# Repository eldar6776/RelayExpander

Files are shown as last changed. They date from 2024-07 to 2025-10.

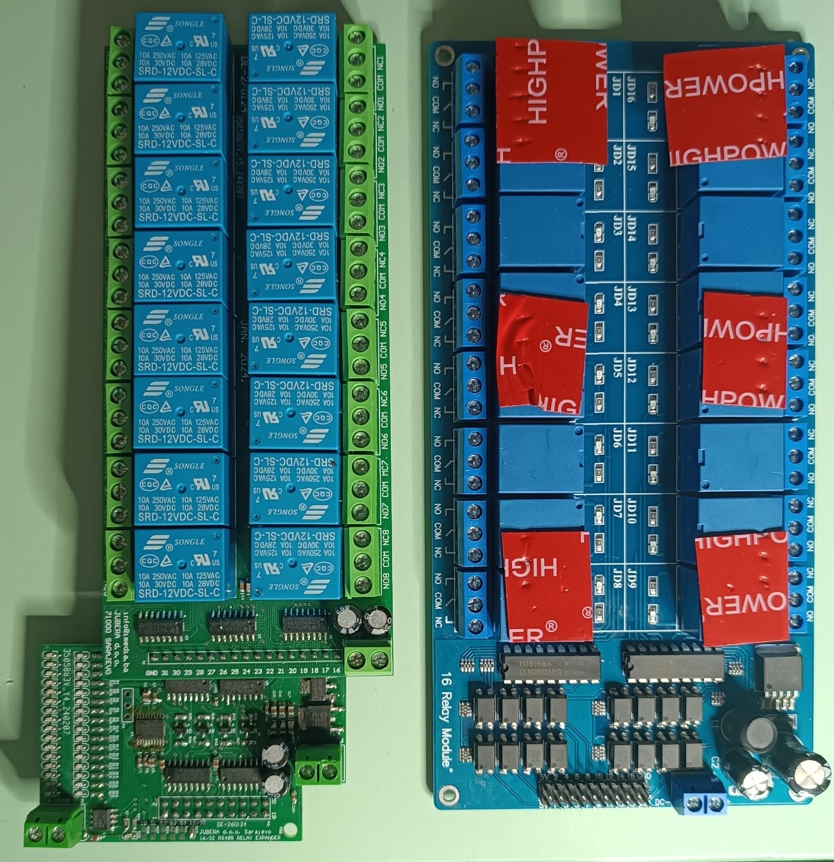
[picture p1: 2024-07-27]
doc/RelayExpander_1.jpg

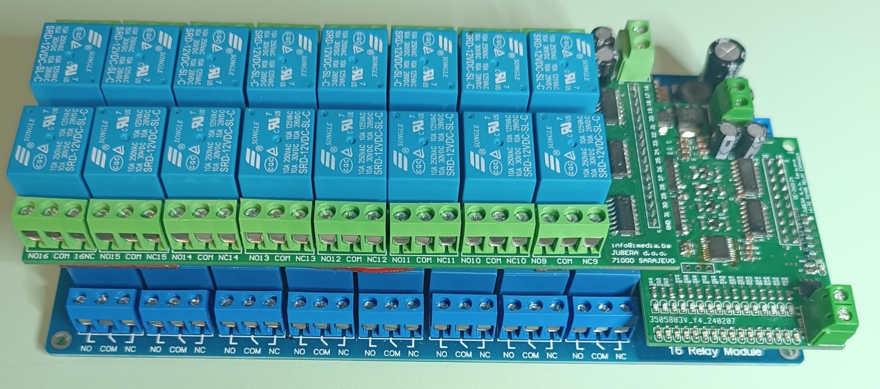
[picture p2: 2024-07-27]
doc/RelayExpander_2.jpg

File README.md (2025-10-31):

# RS485 16x Relay Expander

Ovaj projekat predstavlja adresirani RS485 ekspander za upravljanje do 16 releja putem serijske komunikacije. Namenjen je za automatizaciju, industrijske sisteme, pametne kuće i druge aplikacije gde je potrebno pouzdano i fleksibilno upravljanje velikim brojem releja na daljinu.

## Karakteristike

- **Broj releja:** 16
- **Komunikacija:** RS485 (Modbus ili custom protokol)
- **Napajanje:** 12V DC
- **Maksimalna struja kontakta:**  10A
- **Adresabilnost:** Svaka ploča može imati sopstvenu adresu na magistrali
- **Indikacija:** LED indikatori za stanje svakog releja

## Upotreba

1. **Povezivanje:** Povežite ekspander na RS485 magistralu i napajanje.
2. **Konfiguracija adrese:** (Unesite postupak podešavanja adrese, DIP prekidači, softverski itd.)
3. **Komunikacija:** Koristite Modbus RTU ili prilagođeni serijski protokol za upravljanje relejima.
4. **Komande:** Primeri serijskih komandi za uključivanje/isključivanje releja.

## Primer serijske komande

```
<adresa> <komanda> <relej> <stanje>
```
- adresa: adresa ekspandera na magistrali
- komanda: SET
- relej: broj releja (1-16)
- stanje: ON/OFF

## Hardver

- [Shema povezivanja](shema.pdf)  (https://github.com/eldar6776/RelayExpander/blob/main/hw/DE-260124/DE-260124.pdf)
- [PCB dizajn](pcb_files/)    ([hw](https://github.com/eldar6776/RelayExpander/tree/main/hw))

## Softver

- Primer Modbus biblioteke za Arduino/Python/C
- Firmware za mikrokontroler (ako postoji)

## Instalacija

1. Preuzmite ili klonirajte repozitorijum:
   ```
   git clone https://github.com/eldar6776/RelayExpander.git
   ```
2. Pratite uputstva za montažu i povezivanje u dokumentaciji.

## Kontakt

Za dodatne informacije, predloge ili izveštaje o greškama, kontaktirajte autora putem [GitHub Issues](https://github.com/eldar6776/RelayExpander/issues) ili emaila.

---

**Napomena:** Ovaj projekat je open-source. Slobodno ga koristite, modifikujte i doprinosite razvoju!

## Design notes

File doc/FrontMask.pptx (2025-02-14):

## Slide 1

LUX-TH16-140824

0 1 2 3 4 5 6 7

8 9 10 11 12 13 14 15

JUBERA d.o.o. Sarajevo
www.imedia.ba

SELECT SET

A0 A1 A2 A3 A4 A5

ADDRESS

LUX-TH16-140824

0 1 2 3 4 5 6 7

8 9 10 11 12 13 14 15

JUBERA d.o.o. Sarajevo
www.imedia.ba

SELECT SET

A0 A1 A2 A3 A4 A5

ADDRESS

ALL CHANNELS 10A max. / SINGLE 2A max. / 400Vac max.

O7 O6 O5 O4 O3 O2 O1 O0 L1 +12V GND

O7 O6 O5 O4 O3 O2 O1 O0 L1 +12V GND

A RS485 B O15 O14 O13 O12 O11 O10 O9 O8 L2

ALL CHANNELS 10A max. / SINGLE 2A max. / 400Vac max.

A RS485 B O15 O14 O13 O12 O11 O10 O9 O8 L2

ALL CHANNELS 10A max. / SINGLE 2A max. / 400Vac max.

O7 O6 O5 O4 O3 O2 O1 O0 L1 +12V GND

O7 O6 O5 O4 O3 O2 O1 O0 L1 +12V GND

A RS485 B O15 O14 O13 O12 O11 O10 O9 O8 L2

ALL CHANNELS 10A max. / SINGLE 2A max. / 400Vac max.

A RS485 B O15 O14 O13 O12 O11 O10 O9 O8 L2

ALL CHANNELS 10A max. / SINGLE 2A max. / 400Vac max.

O7 O6 O5 O4 O3 O2 O1 O0 L1 +12V GND

O7 O6 O5 O4 O3 O2 O1 O0 L1 +12V GND

A RS485 B O15 O14 O13 O12 O11 O10 O9 O8 L2

ALL CHANNELS 10A max. / SINGLE 2A max. / 400Vac max.

A RS485 B O15 O14 O13 O12 O11 O10 O9 O8 L2

ALL CHANNELS 10A max. / SINGLE 2A max. / 400Vac max.

O7 O6 O5 O4 O3 O2 O1 O0 L1 +12V GND

O7 O6 O5 O4 O3 O2 O1 O0 L1 +12V GND

A RS485 B O15 O14 O13 O12 O11 O10 O9 O8 L2

ALL CHANNELS 10A max. / SINGLE 2A max. / 400Vac max.

A RS485 B O15 O14 O13 O12 O11 O10 O9 O8 L2

LUX-TH16-140824

0 1 2 3 4 5 6 7

8 9 10 11 12 13 14 15

JUBERA d.o.o. Sarajevo
www.imedia.ba

SELECT SET

A0 A1 A2 A3 A4 A5

ADDRESS

LUX-TH16-140824

0 1 2 3 4 5 6 7

8 9 10 11 12 13 14 15

JUBERA d.o.o. Sarajevo
www.imedia.ba

SELECT SET

A0 A1 A2 A3 A4 A5

ADDRESS

LUX-TH16-140824

0 1 2 3 4 5 6 7

8 9 10 11 12 13 14 15

JUBERA d.o.o. Sarajevo
www.imedia.ba

SELECT SET

A0 A1 A2 A3 A4 A5

ADDRESS

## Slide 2

LUX-JL8-120824

0 1 2 3 4 5 6 7

JUBERA d.o.o. Sarajevo
www.imedia.ba

UP

SEL

DN

A0 A1 A2 A3 A4 A5

ADDRESS

LUX-JL8-120824

0 1 2 3 4 5 6 7

JUBERA d.o.o. Sarajevo
www.imedia.ba

UP

SEL

DN

A0 A1 A2 A3 A4 A5

ADDRESS

ALL CHANNELS 10A max. / SINGLE 2A max. / 400Vac max.

3DN 3UP 2DN 2UP 1DN 1UP 0DN 0UP L1 +12V GND

3DN 3UP 2DN 2UP 1DN 1UP 0DN 0UP L1 +12V GND

A RS485 B 7DN 7UP 6DN 6UP 5DN 5UP 4DN 4UP

ALL CHANNELS 10A max. / SINGLE 2A max. / 400Vac max.

A RS485 B 7DN 7UP 6DN 6UP 5DN 5UP 4DN 4UP

L1

ALL CHANNELS 10A max. / SINGLE 2A max. / 400Vac max.

3DN 3UP 2DN 2UP 1DN 1UP 0DN 0UP L1 +12V GND

3DN 3UP 2DN 2UP 1DN 1UP 0DN 0UP L1 +12V GND

A RS485 B 7DN 7UP 6DN 6UP 5DN 5UP 4DN 4UP

ALL CHANNELS 10A max. / SINGLE 2A max. / 400Vac max.

A RS485 B 7DN 7UP 6DN 6UP 5DN 5UP 4DN 4UP

L1

LUX-JL8-120824

0 1 2 3 4 5 6 7

JUBERA d.o.o. Sarajevo
www.imedia.ba

UP

SEL

DN

A0 A1 A2 A3 A4 A5

ADDRESS

ALL CHANNELS 10A max. / SINGLE 2A max. / 400Vac max.

3DN 3UP 2DN 2UP 1DN 1UP 0DN 0UP L1 +12V GND

3DN 3UP 2DN 2UP 1DN 1UP 0DN 0UP L1 +12V GND

A RS485 B 7DN 7UP 6DN 6UP 5DN 5UP 4DN 4UP

ALL CHANNELS 10A max. / SINGLE 2A max. / 400Vac max.

A RS485 B 7DN 7UP 6DN 6UP 5DN 5UP 4DN 4UP

L1

ALL CHANNELS 10A max. / SINGLE 2A max. / 400Vac max.

3DN 3UP 2DN 2UP 1DN 1UP 0DN 0UP L1 +12V GND

3DN 3UP 2DN 2UP 1DN 1UP 0DN 0UP L1 +12V GND

A RS485 B 7DN 7UP 6DN 6UP 5DN 5UP 4DN 4UP

ALL CHANNELS 10A max. / SINGLE 2A max. / 400Vac max.

A RS485 B 7DN 7UP 6DN 6UP 5DN 5UP 4DN 4UP

L1

LUX-JL8-120824

0 1 2 3 4 5 6 7

JUBERA d.o.o. Sarajevo
www.imedia.ba

UP

SEL

DN

A0 A1 A2 A3 A4 A5

ADDRESS

LUX-JL8-120824

0 1 2 3 4 5 6 7

JUBERA d.o.o. Sarajevo
www.imedia.ba

UP

SEL

DN

A0 A1 A2 A3 A4 A5

ADDRESS

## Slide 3

LUX-RE8-211024

0 1 2 3 4 5 6 7

JUBERA d.o.o. Sarajevo
www.imedia.ba

SEL

SET

A0 A1 A2 A3 A4 A5

ADDRESS

LUX-RE8-211024

0 1 2 3 4 5 6 7

JUBERA d.o.o. Sarajevo
www.imedia.ba

SEL

SET

A0 A1 A2 A3 A4 A5

ADDRESS

ONE CHANNEL 8A max. / 400Vac max.

NO4 CM4 NO3 CM3 NO2 CM2 NC2 NC1 CM1 NO1 +12V GND

NO4 CM4 NO3 CM3 NO2 CM2 NC2 NC1 CM1 NO1 +12V GND

A RS485 B NO8 CM8 NO7 CM7 NO6 CM6 NC6 NC5 CM5 NC5

ONE CHANNEL 8A max. / 400Vac max.

A RS485 B NO8 CM8 NO7 CM7 NO6 CM6 NC6 NC5 CM5 NC5

ONE CHANNEL 8A max. / 400Vac max.

NO4 CM4 NO3 CM3 NO2 CM2 NC2 NC1 CM1 NO1 +12V GND

NO4 CM4 NO3 CM3 NO2 CM2 NC2 NC1 CM1 NO1 +12V GND

A RS485 B NO8 CM8 NO7 CM7 NO6 CM6 NC6 NC5 CM5 NC5

ONE CHANNEL 8A max. / 400Vac max.

A RS485 B NO8 CM8 NO7 CM7 NO6 CM6 NC6 NC5 CM5 NC5

LUX-RE8-211024

0 1 2 3 4 5 6 7

JUBERA d.o.o. Sarajevo
www.imedia.ba

SEL

SET

A0 A1 A2 A3 A4 A5

ADDRESS

ONE CHANNEL 8A max. / 400Vac max.

NO4 CM4 NO3 CM3 NO2 CM2 NC2 NC1 CM1 NO1 +12V GND

NO4 CM4 NO3 CM3 NO2 CM2 NC2 NC1 CM1 NO1 +12V GND

A RS485 B NO8 CM8 NO7 CM7 NO6 CM6 NC6 NC5 CM5 NC5

ONE CHANNEL 8A max. / 400Vac max.

A RS485 B NO8 CM8 NO7 CM7 NO6 CM6 NC6 NC5 CM5 NC5

ONE CHANNEL 8A max. / 400Vac max.

NO4 CM4 NO3 CM3 NO2 CM2 NC2 NC1 CM1 NO1 +12V GND

NO4 CM4 NO3 CM3 NO2 CM2 NC2 NC1 CM1 NO1 +12V GND

A RS485 B NO8 CM8 NO7 CM7 NO6 CM6 NC6 NC5 CM5 NC5

ONE CHANNEL 8A max. / 400Vac max.

A RS485 B NO8 CM8 NO7 CM7 NO6 CM6 NC6 NC5 CM5 NC5

LUX-RE8-211024

0 1 2 3 4 5 6 7

JUBERA d.o.o. Sarajevo
www.imedia.ba

SEL

SET

A0 A1 A2 A3 A4 A5

ADDRESS

LUX-RE8-211024

0 1 2 3 4 5 6 7

JUBERA d.o.o. Sarajevo
www.imedia.ba

SEL

SET

A0 A1 A2 A3 A4 A5

ADDRESS

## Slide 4

LUX-DM4-180824

1 2 3 4

UP

JUBERA d.o.o. Sarajevo
www.imedia.ba

SEL

DN

A0 A1 A2 A3 A4 A5

ADDRESS

LUX-DM4-180824

1 2 3 4

UP

JUBERA d.o.o. Sarajevo
www.imedia.ba

SEL

DN

A0 A1 A2 A3 A4 A5

ADDRESS

ONE CHANNEL 2A max. / 400Vac max.

N3 CH3 L3 N4 CH4 L4 +12V GND

N3 CH3 L3 N4 CH4 L4 +12V GND

A RS485 B N2 CH2 L2 N1 CH1 L1

A RS485 B N2 CH2 L2 N1 CH1 L1

ONE CHANNEL 2A max. / 400Vac max.

ONE CHANNEL 2A max. / 400Vac max.

N3 CH3 L3 N4 CH4 L4 +12V GND

N3 CH3 L3 N4 CH4 L4 +12V GND

A RS485 B N2 CH2 L2 N1 CH1 L1

ONE CHANNEL 2A max. / 400Vac max.

A RS485 B N2 CH2 L2 N1 CH1 L1

LUX-DM4-180824

1 2 3 4

UP

JUBERA d.o.o. Sarajevo
www.imedia.ba

SEL

DN

A0 A1 A2 A3 A4 A5

ADDRESS

ONE CHANNEL 2A max. / 400Vac max.

N3 CH3 L3 N4 CH4 L4 +12V GND

N3 CH3 L3 N4 CH4 L4 +12V GND

A RS485 B N2 CH2 L2 N1 CH1 L1

ONE CHANNEL 2A max. / 400Vac max.

A RS485 B N2 CH2 L2 N1 CH1 L1

ONE CHANNEL 2A max. / 400Vac max.

N3 CH3 L3 N4 CH4 L4 +12V GND

N3 CH3 L3 N4 CH4 L4 +12V GND

A RS485 B N2 CH2 L2 N1 CH1 L1

ONE CHANNEL 2A max. / 400Vac max.

A RS485 B N2 CH2 L2 N1 CH1 L1

LUX-DM4-180824

1 2 3 4

UP

JUBERA d.o.o. Sarajevo
www.imedia.ba

SEL

DN

A0 A1 A2 A3 A4 A5

ADDRESS

LUX-DM4-180824

1 2 3 4

UP

JUBERA d.o.o. Sarajevo
www.imedia.ba

SEL

DN

A0 A1 A2 A3 A4 A5

ADDRESS

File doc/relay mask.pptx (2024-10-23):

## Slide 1

RELAY
1 2 3 4 5 6 7 8

>>

ON/OFF

BUS ADDR.

ON-------------------------

A0 A1 A2 A3 A4 A5

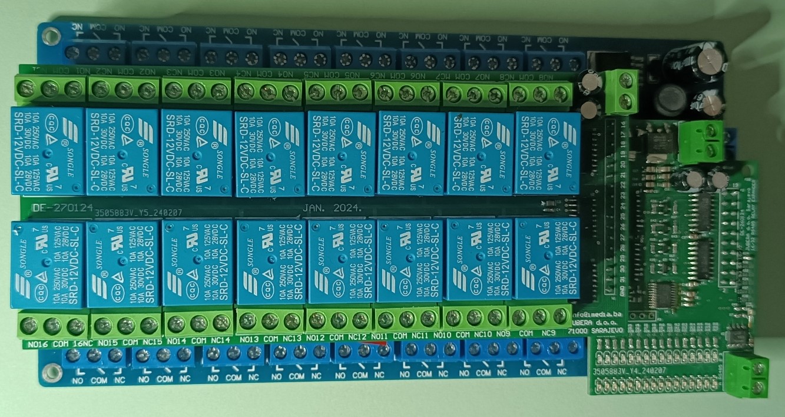
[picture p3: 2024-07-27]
doc/RelayExpander_3.jpg

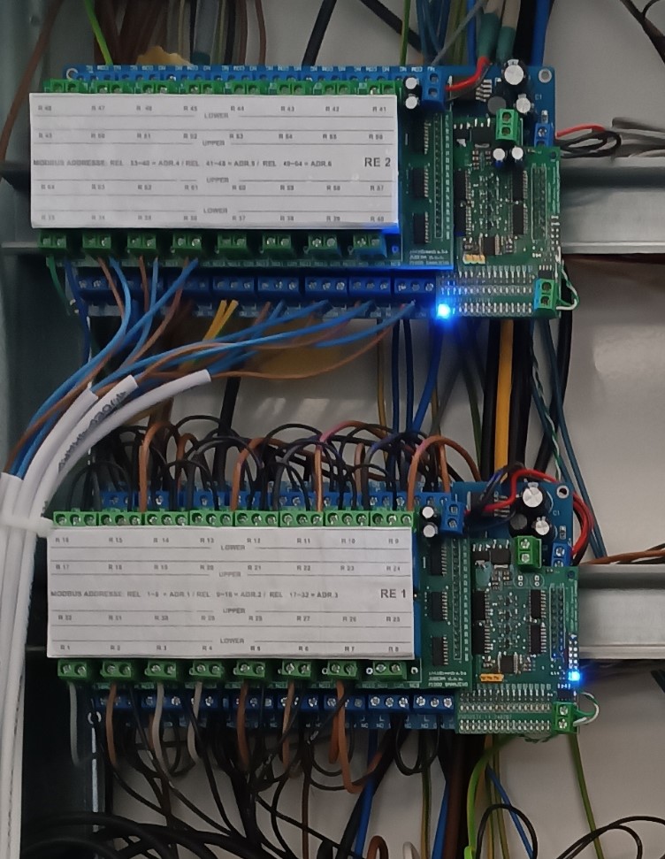
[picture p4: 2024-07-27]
doc/RelayExpander_4.jpg

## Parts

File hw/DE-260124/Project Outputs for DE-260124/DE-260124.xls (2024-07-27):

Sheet: BOM Report
Bill of Materials |  |  | Bill of Materials For Project [DE-260124.PrjPcb] (No PCB Document Selected)
Source Data From: |  | DE-260124.PrjPcb
Project: |  | DE-260124.PrjPcb
Variant: |  | None
Creation Date: | 27. 1. 2024. | 10:55:52
Print Date: | 45318 | 45318.45558
Footprint | Comment | LibRef | Designator | Description | Quantity
0603 | 100nF | C0603 | C1, C2, C3, C4, C5, C7, C10, C11, C13, C15, C18 | Ceramic Chip Capacitor - Standard | 11
0805 | 4u7 | C0805 | C6 | Ceramic Chip Capacitor - Standard | 1
0603 | 1uF | C0603 | C8 | Ceramic Chip Capacitor - Standard | 1
0603 | 10nF | C0603 | C9 | Ceramic Chip Capacitor - Standard | 1
0805 | 10uF | C0805 | C12, C16, C17 | Ceramic Chip Capacitor - Standard | 3
CAPPR2-5X11 | 22uF | EKA00AA247F00 | C14, C19 | Aluminum Electrolytic Capacitor, Radial Style with Long Leads: 47uF, 35V | 2
1.6X0.8X0.8 | LED_RED | HSMZ-C190 | D1, D2, D3, D4, D5, D6, D7, D8, D9, D10, D11, D12, D13, D14, D15, D16, D17, D18, D19, D20, D21, D22, D23, D24, D25, D26, D27, D28, D29, D30, D31, D32, D33 | High Performance Chip LED, Red | 33
TERMINAL BLOK 2 | TERMINAL BLOK 2 | TERMINAL BLOK 2 | P1, P5 | 2 pinski terminal blok | 2
HDR2X10 | Header 10X2 | Header 10X2 | P2 | Header, 10-Pin, Dual row | 1
HDR1X3 | ICSP | Header 3 | P3 | Header, 3-Pin | 1
HDR1X17 | Header 17 | Header 17 | P4 | Header, 17-Pin | 1
SOT23_N | MMBT2222 | BC817 | Q1 | NPN General-purpose Transistor | 1
SOT23_N | BSS123 | BSS123 | Q2, Q3, Q4 | N-channel Enhancement Mode Vertical D-MOSFET | 3
ERA-0603 | 3K3 | ERA3Y | R1, R2, R3, R4, R5, R6, R8, R9, R10, R11, R12, R13, R14, R15, R16, R18, R20, R21, R22, R23, R24, R25, R28, R30, R33, R39, R40, R41, R44, R45, R46, R47, R48 | Rectangular Thick Film Chip Resistor, 10 Ohm to 330k Ohm Range, 0.1% and 0.5% Tolerance, 0603 Size, 0.063 W | 33
ERA-0603 | 1K | ERA6Y | R7 | Rectangular Thick Film Chip Resistor, 10 Ohm to 1M Ohm Range, 0.1% and 0.5% Tolerance, 0805 Size, 0.1 W | 1
ERA-0603 | 10K | ERA6Y | R17, R19, R26, R27, R35, R36, R42, R43 | Rectangular Thick Film Chip Resistor, 10 Ohm to 1M Ohm Range, 0.1% and 0.5% Tolerance, 0805 Size, 0.1 W | 8
ERA-0603 | NF | ERA6Y | R29, R31, R32, R34, R37, R38 | Rectangular Thick Film Chip Resistor, 10 Ohm to 1M Ohm Range, 0.1% and 0.5% Tolerance, 0805 Size, 0.1 W | 6
D016_N | SN74HC595D | SN74HC595D | U1, U3, U5, U6 | 8-Bit Shift Register with 3-State Output Registers | 4
D008_L | MAX485 | SN75176BD | U2 | Differential Bus Transceiver | 1
STM-TSSOP20_N | STM32F030F4P6 | STM32F030F4P6 | U4 | ARM Cortex-M0 32-bit MCU, 16 KB Flash, 4 KB Internal RAM, 15 I/Os, 20-pin TSSOP, -40 to 85 degC, Tube | 1
TO-252_N | L78M05CDT-TR | L78M05CDT-TR | U7 | Positive Voltage Regulator, 5V, 3-Pin DPAK, Tape and Reel | 1
ZZ311 | REG1117-3.3 | REG1117-3.3 | U8 | 800mA and 1A Low Dropout Positive Regulator 2.85V, 3.3V, 5V, and Adjustable | 1
 |  |  |  |  | 117
Approved |  | Notes

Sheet: Project Information
Project Full Path | H:\OneDrive\Desktop\DE-260124\DE-260124.PrjPcb
Project Filename | DE-260124.PrjPcb
Variant Name | None
Data-Source Filename | DE-260124.PrjPcb
Data-Source Full Path | H:\OneDrive\Desktop\DE-260124\DE-260124.PrjPcb
Title | Bill of Materials For Project [DE-260124.PrjPcb] (No PCB Document Selected)
Total Quantity | 117
Report Time | 10:55:52
Report Date | 27. 1. 2024.
Report Date & Tine | 27. 1. 2024. 10:55:52
Output Name | Bill of Materials
Output Type | BOM_PartType
Output Generator Name | BOM
Output Generator Description | Bill of Materials

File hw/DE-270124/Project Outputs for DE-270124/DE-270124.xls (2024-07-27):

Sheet: BOM Report
Bill of Materials |  |  | Bill of Materials For PCB Document [DE-270124.PcbDoc]
Source Data From: |  | DE-270124.PcbDoc
Project: |  | DE-270124.PrjPcb
Variant: |  | None
Creation Date: | 27. 1. 2024. | 17:45:43
Print Date: | 45318 | 45318.74013
Footprint | Comment | LibRef | Designator | Description | Quantity
CAPPR2-5X11 | 22uF | EKA00AA247F00 | C1, C2 | Aluminum Electrolytic Capacitor, Radial Style with Long Leads: 47uF, 35V | 2
0805 | 10uF | C0805 | C3 | Ceramic Chip Capacitor - Standard | 1
0603 | 100nF | C0603 | C4 | Ceramic Chip Capacitor - Standard | 1
SRD-12VDC-SL-O | SRD-12VDC | SRD-12VDC-SL-O | K1, K2, K3, K4, K5, K6, K7, K8, K9, K10, K11, K12, K13, K14, K15, K16 | SPDT PCB relay 12Vc coil | 16
HDR1X17 | Header 17 | Header 17 | P1 | Header, 17-Pin | 1
TERMINAL BLOK 3 | TERMINAL BLOK 3 | TERMINAL BLOK 3 | P2, P3, P4, P5, P6, P7, P8, P9, P10, P11, P12, P13, P14, P15, P16, P18 | 3 pinski terminal blok konektor | 16
TERMINAL BLOK 2 | TERMINAL BLOK 2 | TERMINAL BLOK 2 | P17 | 2 pinski terminal blok | 1
SO16_N | ULN2003D | ULN2003D | U1, U2, U3 | Seven Darlington Array | 3
 |  |  |  |  | 41
Approved |  | Notes

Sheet: Project Information
Project Full Path | I:\ProjektiOtvoreni\Sjenica\hw\RELEXP\DE-270124\DE-270124.PrjPcb
Project Filename | DE-270124.PrjPcb
Variant Name | None
Data-Source Filename | DE-270124.PcbDoc
Data-Source Full Path | I:\ProjektiOtvoreni\Sjenica\hw\RELEXP\DE-270124\DE-270124.PcbDoc
Title | Bill of Materials For PCB Document [DE-270124.PcbDoc]
Total Quantity | 41
Report Time | 17:45:43
Report Date | 27. 1. 2024.
Report Date & Tine | 27. 1. 2024. 17:45:43
Output Name | Bill of Materials
Output Type | BOM_PartType
Output Generator Name | BOM
Output Generator Description | Bill of Materials

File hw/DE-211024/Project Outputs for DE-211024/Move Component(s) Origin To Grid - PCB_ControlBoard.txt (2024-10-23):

Move Component(s) Origin to Grid
Filename     : D:\ProjektiOtvoreni\Expanderi\Relay\hw\DE-211024\PCB_ControlBoard.PcbDoc
Date         : 23. 10. 2024.
Time         : 15:09:35
Time Elapsed : 00:00:00

    DIP Component S3-SW DIP-6 (1648mil,4925mil) on Top Layer - Component pads are OFF grid. No action taken.
    Component S2-ON_OFF (288mil,4925mil) on Top Layer - Component pads are OFF grid. No action taken.
    Component S1-> > (288mil,5315mil) on Top Layer - Component pads are OFF grid. No action taken.
    SMT Small Component R19-2K2 (1898mil,5375mil) on Top Layer - Component pads are OFF grid. No action taken.
    SMT Small Component R18-2K2 (1718mil,5375mil) on Top Layer - Component pads are OFF grid. No action taken.
    SMT Small Component R15-2K2 (1538mil,5375mil) on Top Layer - Component pads are OFF grid. No action taken.
    SMT Small Component R14-2K2 (1358mil,5375mil) on Top Layer - Component pads are OFF grid. No action taken.
    SMT Small Component R13-2K2 (1170mil,5380mil) on Top Layer - Component pads are OFF grid. No action taken.
    SMT Small Component R10-2K2 (998mil,5375mil) on Top Layer - Component pads are OFF grid. No action taken.
    SMT Small Component R8-2K2 (818mil,5375mil) on Top Layer - Component pads are OFF grid. No action taken.
    SMT Small Component R7-2K2 (638mil,5375mil) on Top Layer - Component pads are OFF grid. No action taken.
    DIP Component P1-Header 9X2 (1720mil,5670mil) on Top Layer - Component pads are OFF grid. No action taken.
    SMT Small Component D9-CH8 (1968mil,5309.095mil) on Top Layer - Component pads are OFF grid. No action taken.
    SMT Small Component D8-CH7 (1788mil,5309.095mil) on Top Layer - Component pads are OFF grid. No action taken.
    SMT Small Component D6-CH6 (1608mil,5309.095mil) on Top Layer - Component pads are OFF grid. No action taken.
    SMT Small Component D5-CH5 (1428mil,5309.095mil) on Top Layer - Component pads are OFF grid. No action taken.
    SMT Small Component D4-CH 4 (1248mil,5309.095mil) on Top Layer - Component pads are OFF grid. No action taken.
    SMT Small Component D3-CH 3 (1068mil,5309.095mil) on Top Layer - Component pads are OFF grid. No action taken.
    SMT Small Component D2-CH 2 (888mil,5309.095mil) on Top Layer - Component pads are OFF grid. No action taken.
    SMT Small Component D1-CH 1 (708mil,5309.095mil) on Top Layer - Component pads are OFF grid. No action taken.
    SMT Small Component C2 (288mil,5085mil) on Top Layer - Component pads are OFF grid. No action taken.
    SMT Small Component C1 (288mil,5475mil) on Top Layer - Component pads are OFF grid. No action taken.
count : 22

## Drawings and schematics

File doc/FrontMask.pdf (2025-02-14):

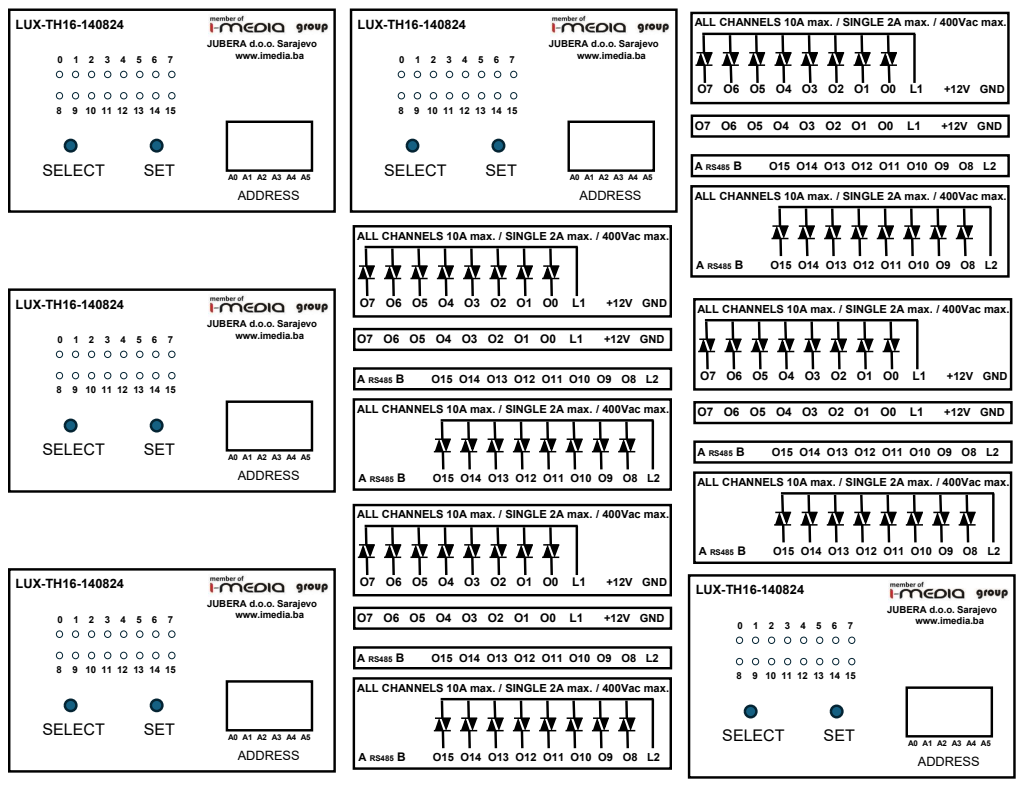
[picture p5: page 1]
+12V GND; LUX-TH16-140824; SELECT; SET; ADDRESS A0 A1 A2 A3 A4 A5

ALL CHANNELS 10A max. / SINGLE 2A max. / 400Vac max.

JUBERA d.o.o. Sarajevo
www.imedia.ba

## SEL

DN

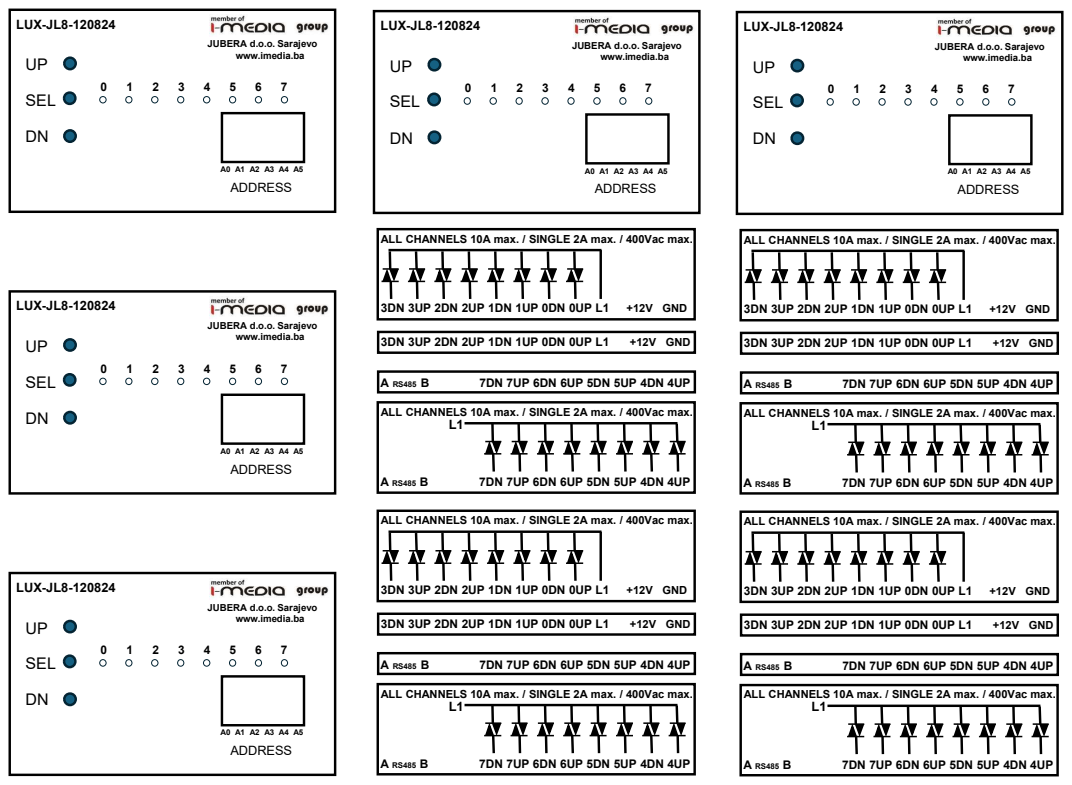
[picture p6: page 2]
ADDRESS; LUX-JL8-120824; SEL; +12V GND

JUBERA d.o.o. Sarajevo
www.imedia.ba

ALL CHANNELS 10A max. / SINGLE 2A max. / 400Vac max.

## SEL

## SEL

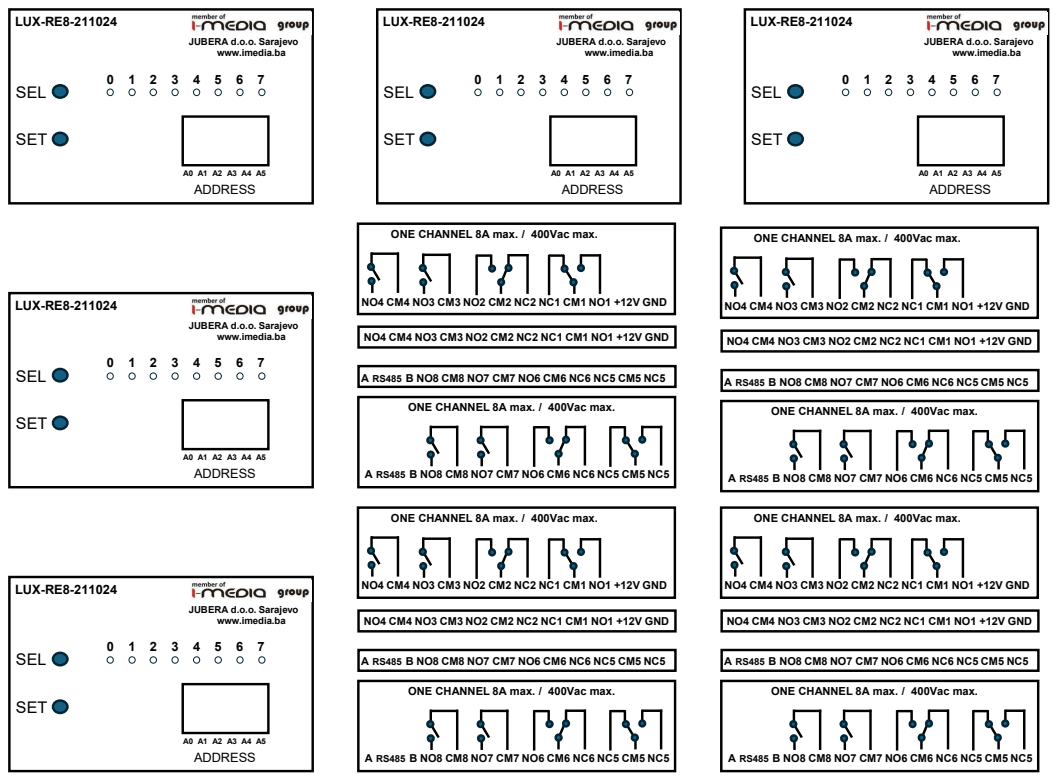
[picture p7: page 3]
SET; A0 A1 A2 A3 A4 A5 ADDRESS; LUX-RE8-211024; SEL; NO4 CM4 NO3 CM3 NO2 CM2 NC2 NC1 CM1 NO1 +12V GND

JUBERA d.o.o. Sarajevo
www.imedia.ba

ONE CHANNEL 8A max. / 400Vac max.

## SEL

DN

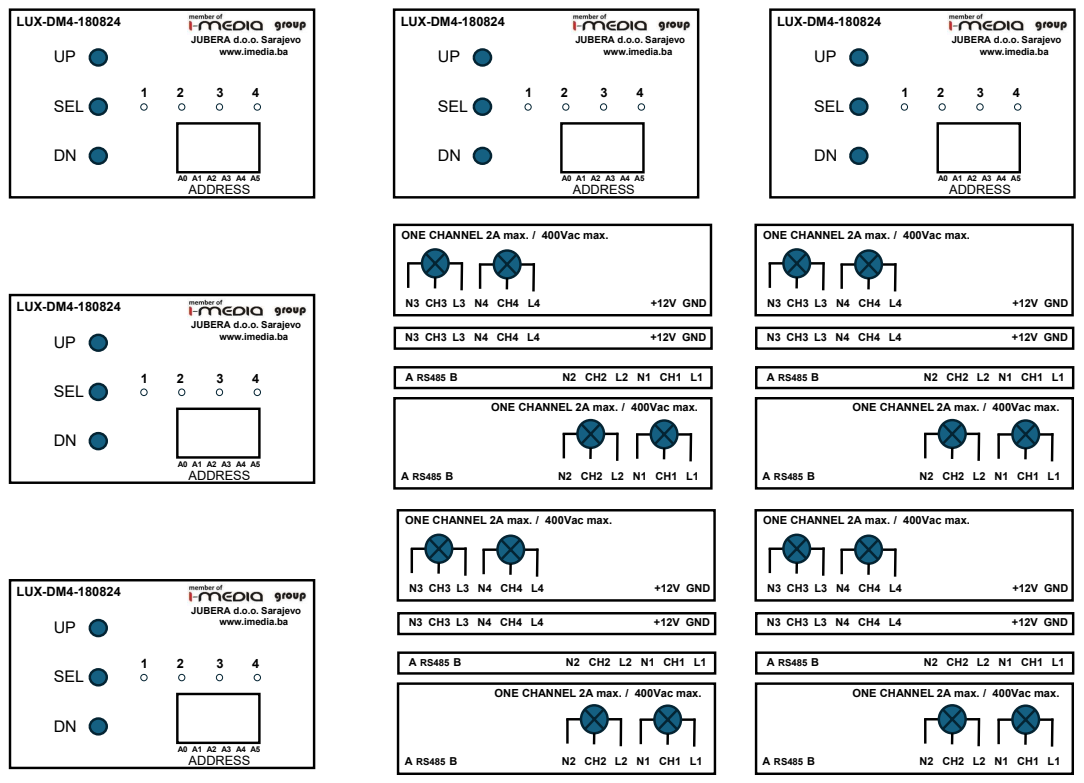
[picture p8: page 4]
ADDRESS; LUX-DM4-180824; SEL; +12V GND

JUBERA d.o.o. Sarajevo
www.imedia.ba

ONE CHANNEL 2A max. / 400Vac max.

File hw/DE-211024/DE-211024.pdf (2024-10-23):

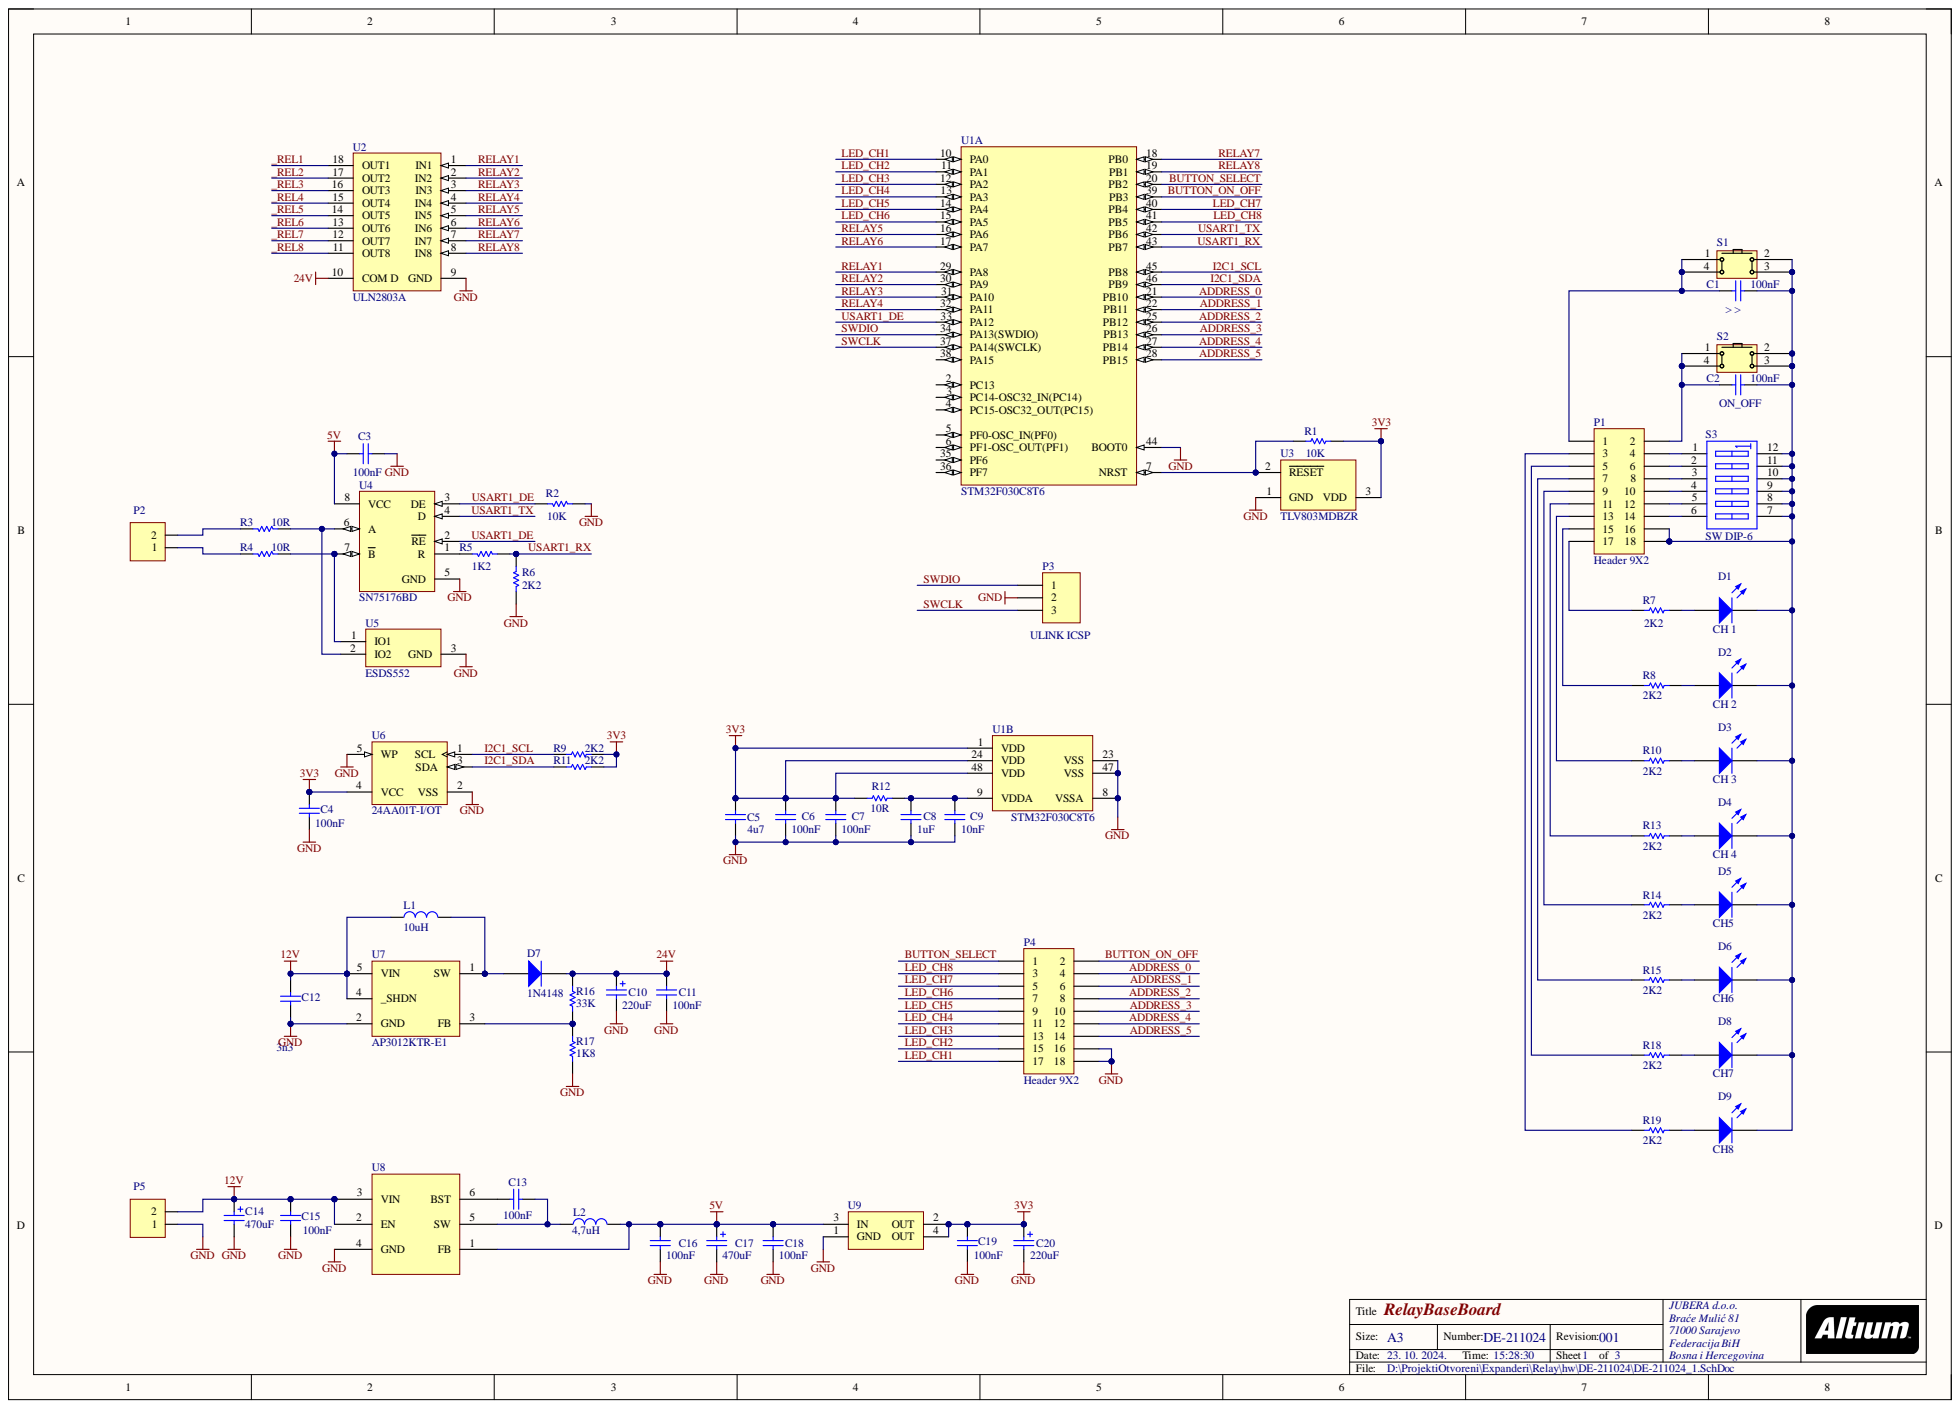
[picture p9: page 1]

D:\ProjektiOtvoreni\Expanderi\Relay\hw\DE-211024\DE-211024_1.SchDoc

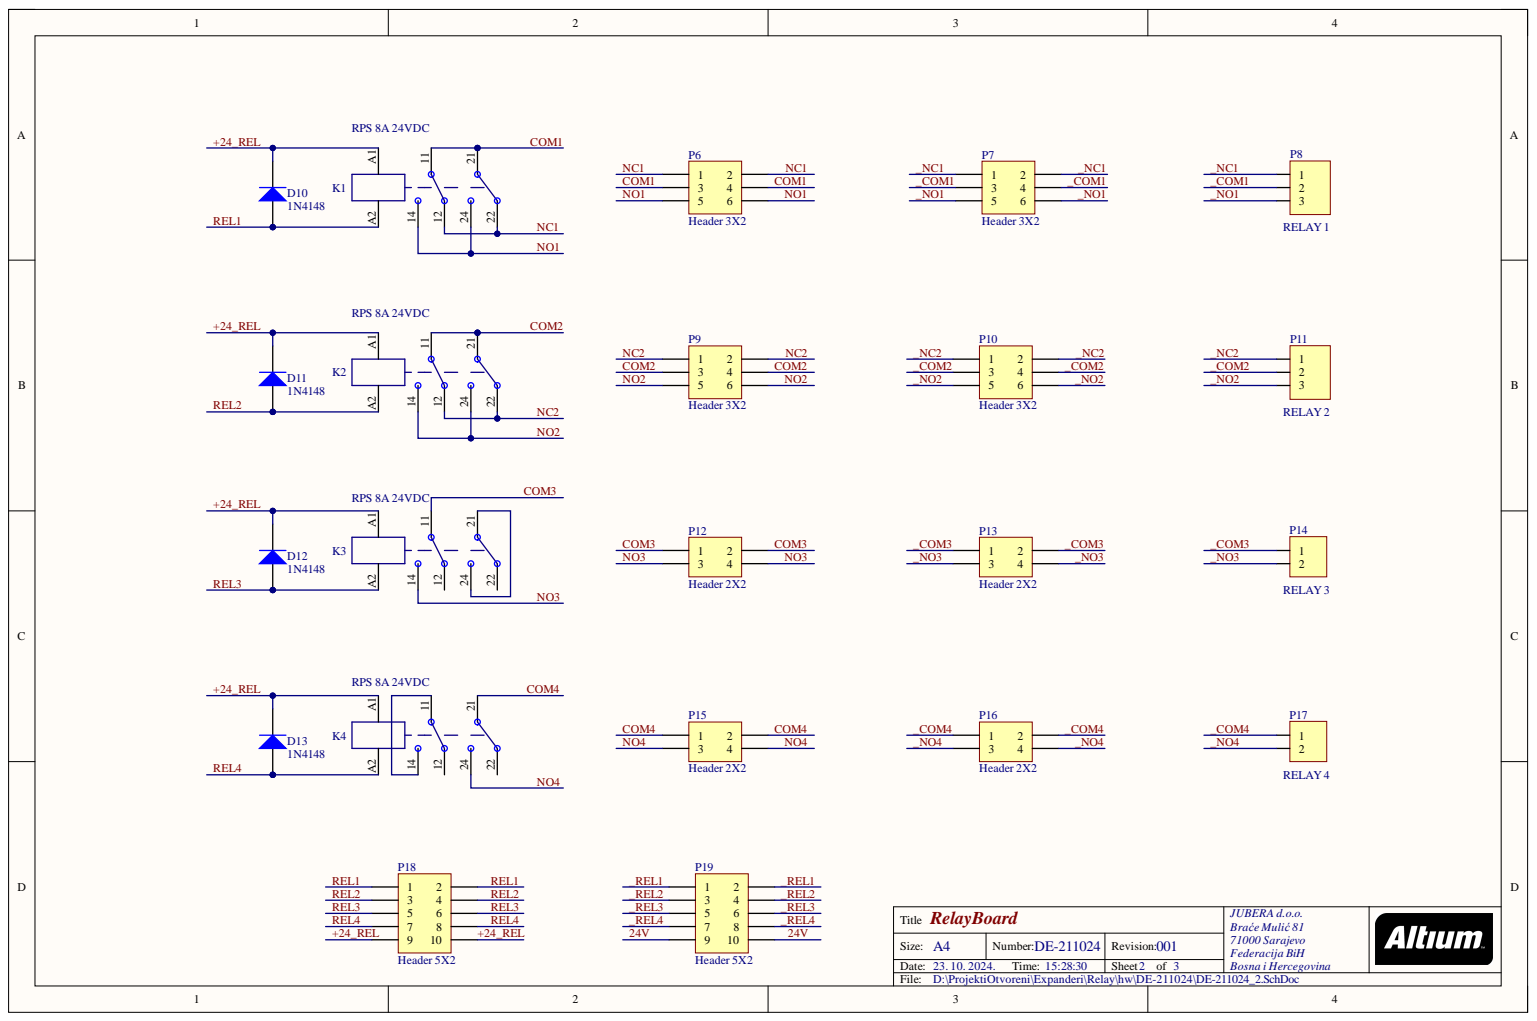
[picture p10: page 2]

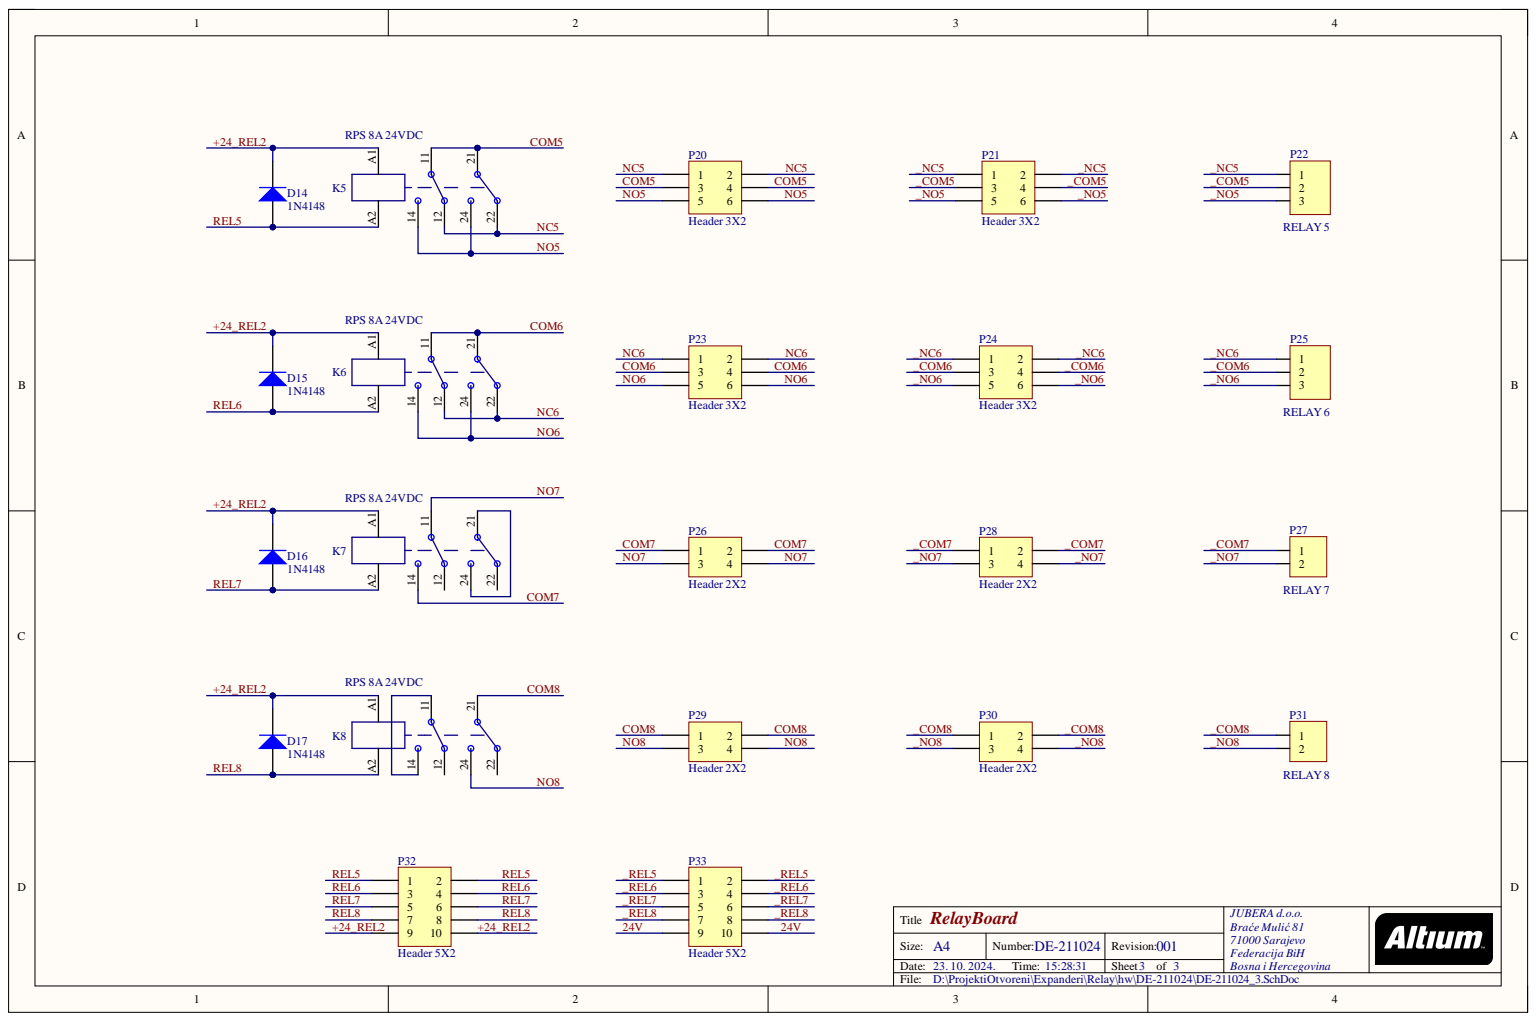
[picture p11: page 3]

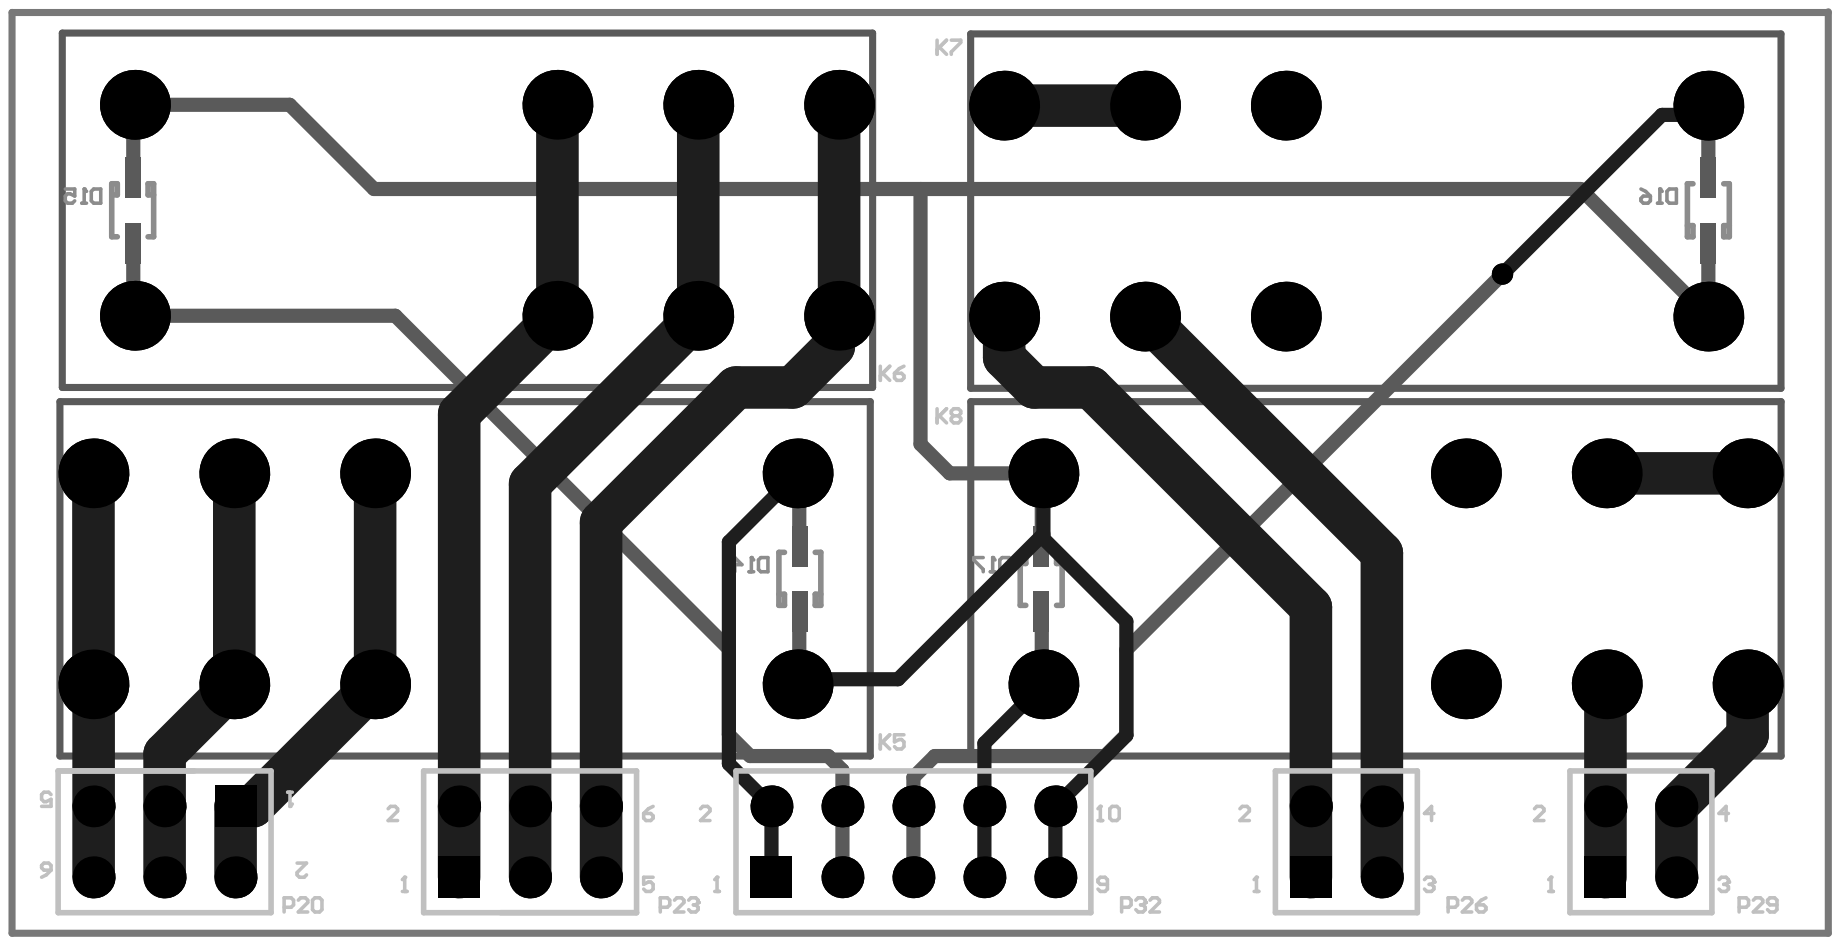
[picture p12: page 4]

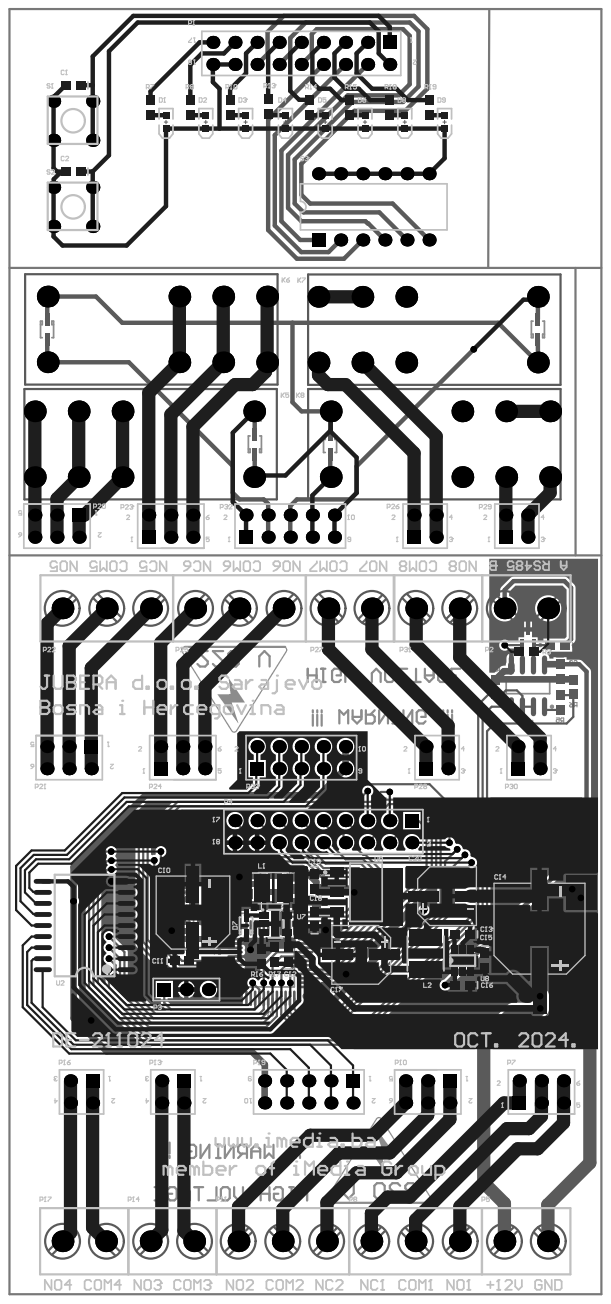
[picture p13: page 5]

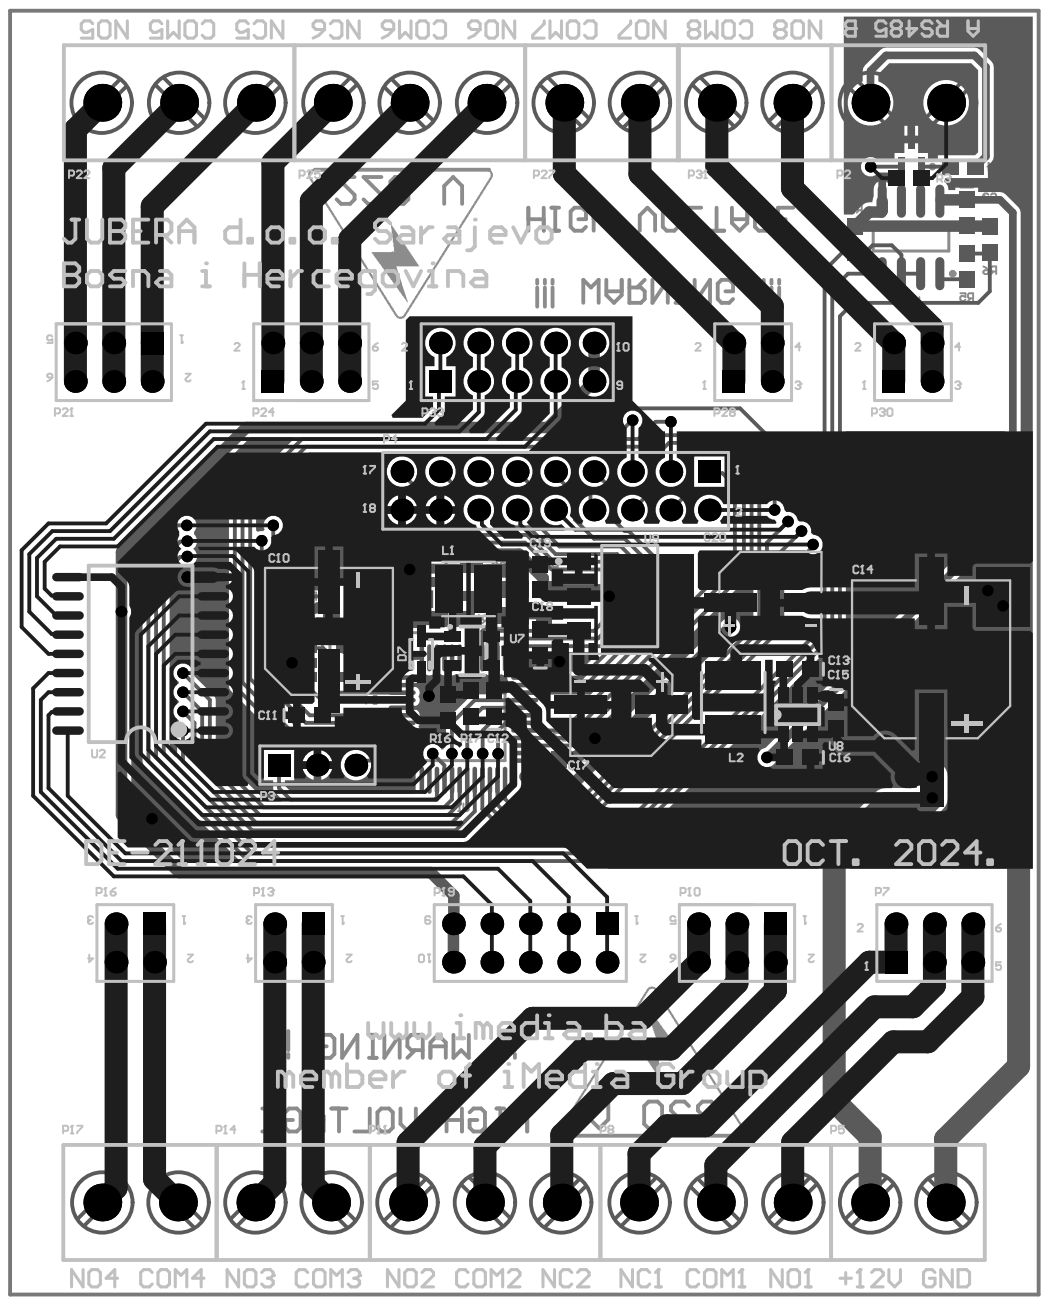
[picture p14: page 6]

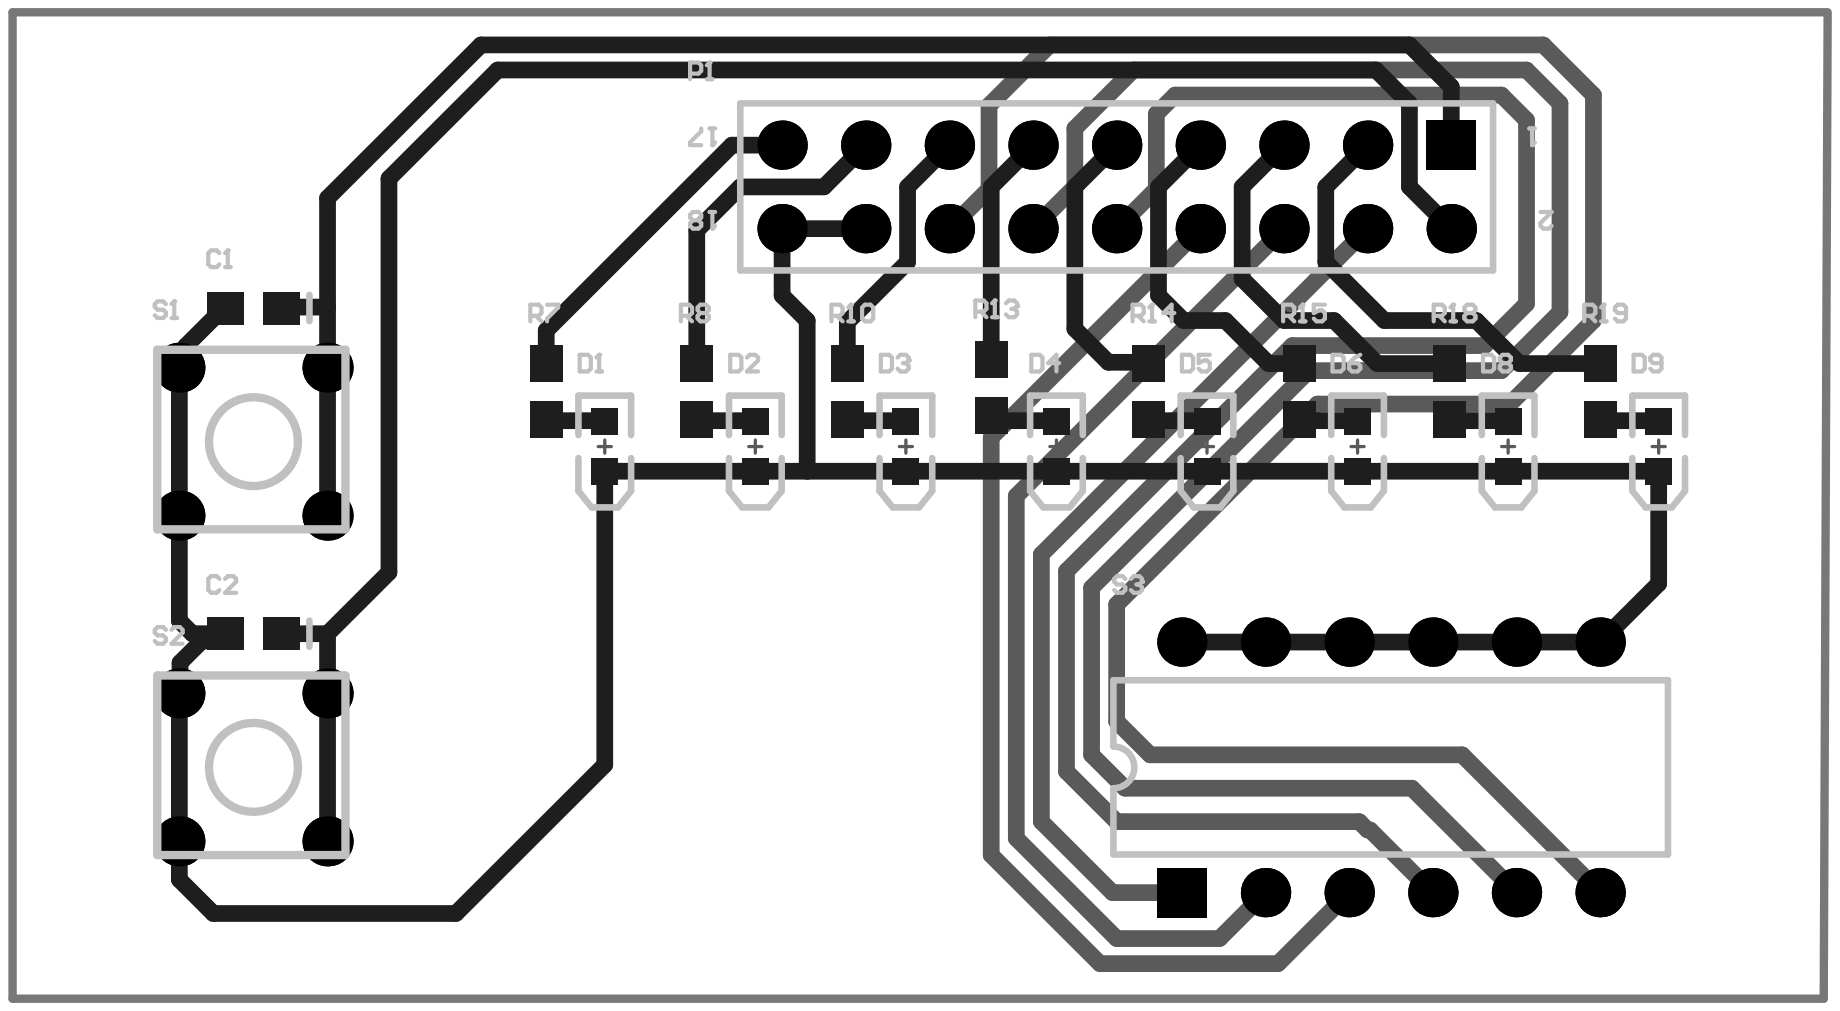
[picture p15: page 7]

Bill of Materials | Bill of Materials for Project [DE-211024.PrjPcb] (No PCB Document Selected)
Source Data From: | DE-211024.PrjPcb
Project: | | DE-211024.PrjPcb
Variant: | | None
Creation Date: 23. 10. 2024. | 15:28
Print Date: | 45588 | 45588,64533
Footprint | Comment | LibRef | Designator | Description | Quantity
603 | C0603 | C1, C2, C4, C11, C13, C15, C16, C18,
C19
Ceramic Chip Capacitor - Standard, Ceramic | 9
603 | 100nF | C0603 | C3, C6, C7 | Ceramic Chip Capacitor - Standard | 3
805 | 4u7 | C0805 | C5 | Ceramic Chip Capacitor - Standard | 1
603 | 1uF | C0603 | C8 | Ceramic Chip Capacitor - Standard | 1
603 | 10nF | C0603 | C9 | Ceramic Chip Capacitor - Standard | 1
SMD,D8xL10.220uF | ROQANG VT1V2C10 | 220uF 35V 195mA@120Hz ±20% SMD,D8x | 1
603 | C0603 | C0603 | C12 | Ceramic Chip Capacitor - Standard | 1
ROQANG VT1470uF | ROQANG VT1C2C14 | 220uF 16V 110mA@120Hz ±20% SMD,D6. | 1
SMD,D6.3xL7470uF | ROQA NG VT1C2C17 | 220uF 16V 110mA@120Hz ±20% SMD,D6. | 1
SMD,D6.3xL7.7mm Aluminum | EROQA NG VT1C2C20 | 220uF 16V 110mA@120Hz ±20% SMD,D6. | 1
1.6X0.8X0.8 | CH 1 | HSMZ-C190 | D1 | High Performance Chip LED, Red | 1
1.6X0.8X0.8 | CH 2 | HSMZ-C190 | D2 | High Performance Chip LED, Red | 1
1.6X0.8X0.8 | CH 3 | HSMZ-C190 | D3 | High Performance Chip LED, Red | 1
1.6X0.8X0.8 | CH 4 | HSMZ-C190 | D4 | High Performance Chip LED, Red | 1
1.6X0.8X0.8 | CH5 | HSMZ-C190 | D5 | High Performance Chip LED, Red | 1
1.6X0.8X0.8 | CH6 | HSMZ-C190 | D6 | High Performance Chip LED, Red | 1
SOD323 | 1N4148 | BAS321 | D7, D10, D11, D12, D13, D14, D15, D16,
D17
General-purpose Diode | 9
1.6X0.8X0.8 | CH7 | HSMZ-C190 | D8 | High Performance Chip LED, Red | 1
1.6X0.8X0.8 | CH8 | HSMZ-C190 | D9 | High Performance Chip LED, Red | 1
RPS 2CO 8A | RPS 8A 24VDC | PCB relay 2CO, | 8K1,K2,K3,K4, K5,K6,K7, K8 | 8
YJYCOIN CD310uH | Inductor | L1 | 1
XRNR4030-4.7uH/M | Inductor | L2 | 2A 4.7uH Magnetic Adhesive Inductor ±20% | 1
HDR2X9 | Header 9X2 | Header 9X2 | P1, P4 | Header, 9-Pin, Dual row | 2
TERMINAL BLOK 2 | TERMINAL BLOKP2, P5 | Terminal blok konektor 3,5 mm | 2
HDR1X3 | ULINK ICSP | Header 3 | P3 | Header, 3-Pin | 1
HDR2X3 | Header 3X2 | Header 3X2 | P6, P7, P9, P10, P20, P21, P23, P24 | Header, 3-Pin, Dual row | 8
TERMINAL BLRELAY 1 | TERMINAL BLOKP8 | 3 pinski terminal blok konektor | 1
TERMINAL BLRELAY 2 | TERMINAL BLOKP11 | 3 pinski terminal blok konektor | 1
HDR2X2 | Header 2X2 | Header 2X2 | P12, P13, P15, P16, P26, P28, P29, P30 | Header, 2-Pin, Dual row | 8
TERMINAL BLRELAY 3 | TERMINAL BLOKP14 | Terminal blok konektor 3,5 mm | 1
TERMINAL BLRELAY 4 | TERMINAL BLOKP17 | Terminal blok konektor 3,5 mm | 1
HDR2X5 | Header 5X2 | Header 5X2 | P18, P19, P32, P33 | Header, 5-Pin, Dual row | 4
TERMINAL BLRELAY 5 | TERMINAL BLOKP22 | 3 pinski terminal blok konektor | 1
TERMINAL BLRELAY 6 | TERMINAL BLOKP25 | 3 pinski terminal blok konektor | 1
TERMINAL BLRELAY 7 | TERMINAL BLOKP27 | Terminal blok konektor 3,5 mm | 1
TERMINAL BLRELAY 8 | TERMINAL BLOKP31 | Terminal blok konektor 3,5 mm | 1
ERA-0603 | 10K | ERA3Y, ERAV | R1, R2 | Rectangular Thick Film Chip Resistor, 10 Oh | 2
ERA-0603 | 10R | ERAV, ERA6Y | R3, R4, R12 | Metal Film Thermosensitive Chip Resistor, 0 | 3
ERA-0603 | 1K2 | ERAV | R5 | Metal Film Thermosensitive Chip Resistor, 0 | 1
ERA-0603 | 2K2 | ERAV, ERA3Y | R6, R7, R8, R9, R10, R11, R13, R14,
R15, R16, R17, R18, R19
Metal Film Thermosensitive Chip Resistor, 0 | 13
TACTILE_SWI>> | TACKTILE_SWITS1 | 1
TACTILE_SWION_OFF | TACKTILE_SWITS2 | 1
DIP-12/SW | SW DIP-6 | SW DIP-6 | S3 | DIP Switch, 6 Position, SPST | 1
STM-LQFP48_STM32F030C8T6STM32F030C8T6U1 | ARM Cortex-M0 32-bit MCU, 64 KB Flash, | 8 | 1
SOIC-18_L11.ULN2803A | ULN2803A | U2 | High-Voltage, High-Current Darlington Array | 1
DBZ3_N | TLV803MDBZR | TLV803MDBZR | U3 | Voltage Supervisor with Active-Low, Open D | 1
D008_N | SN75176BD | SN75176BD | U4 | Differential Bus Transceiver | 1
DCK3_N | ESDS552 | TPD2E007DCKR U5 | ESD Protection Array for AC Signal Data Int | 1
SOT-23-OT5_N24AA01T-I/OT | 24AA01T-I/OT | U6 | 1Kbit, 400kHz, 1.8V, I2C Serial EEPROM, | 5 | 1
SOT-23-5 | AP3012KTR-E1 | AP3012 | U7 | Diodes Incorporated AP3012KTR-E1 Boost | 1
TSOT-26 | AP63200 | U8 | 2A synchronous buck converter | 1
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

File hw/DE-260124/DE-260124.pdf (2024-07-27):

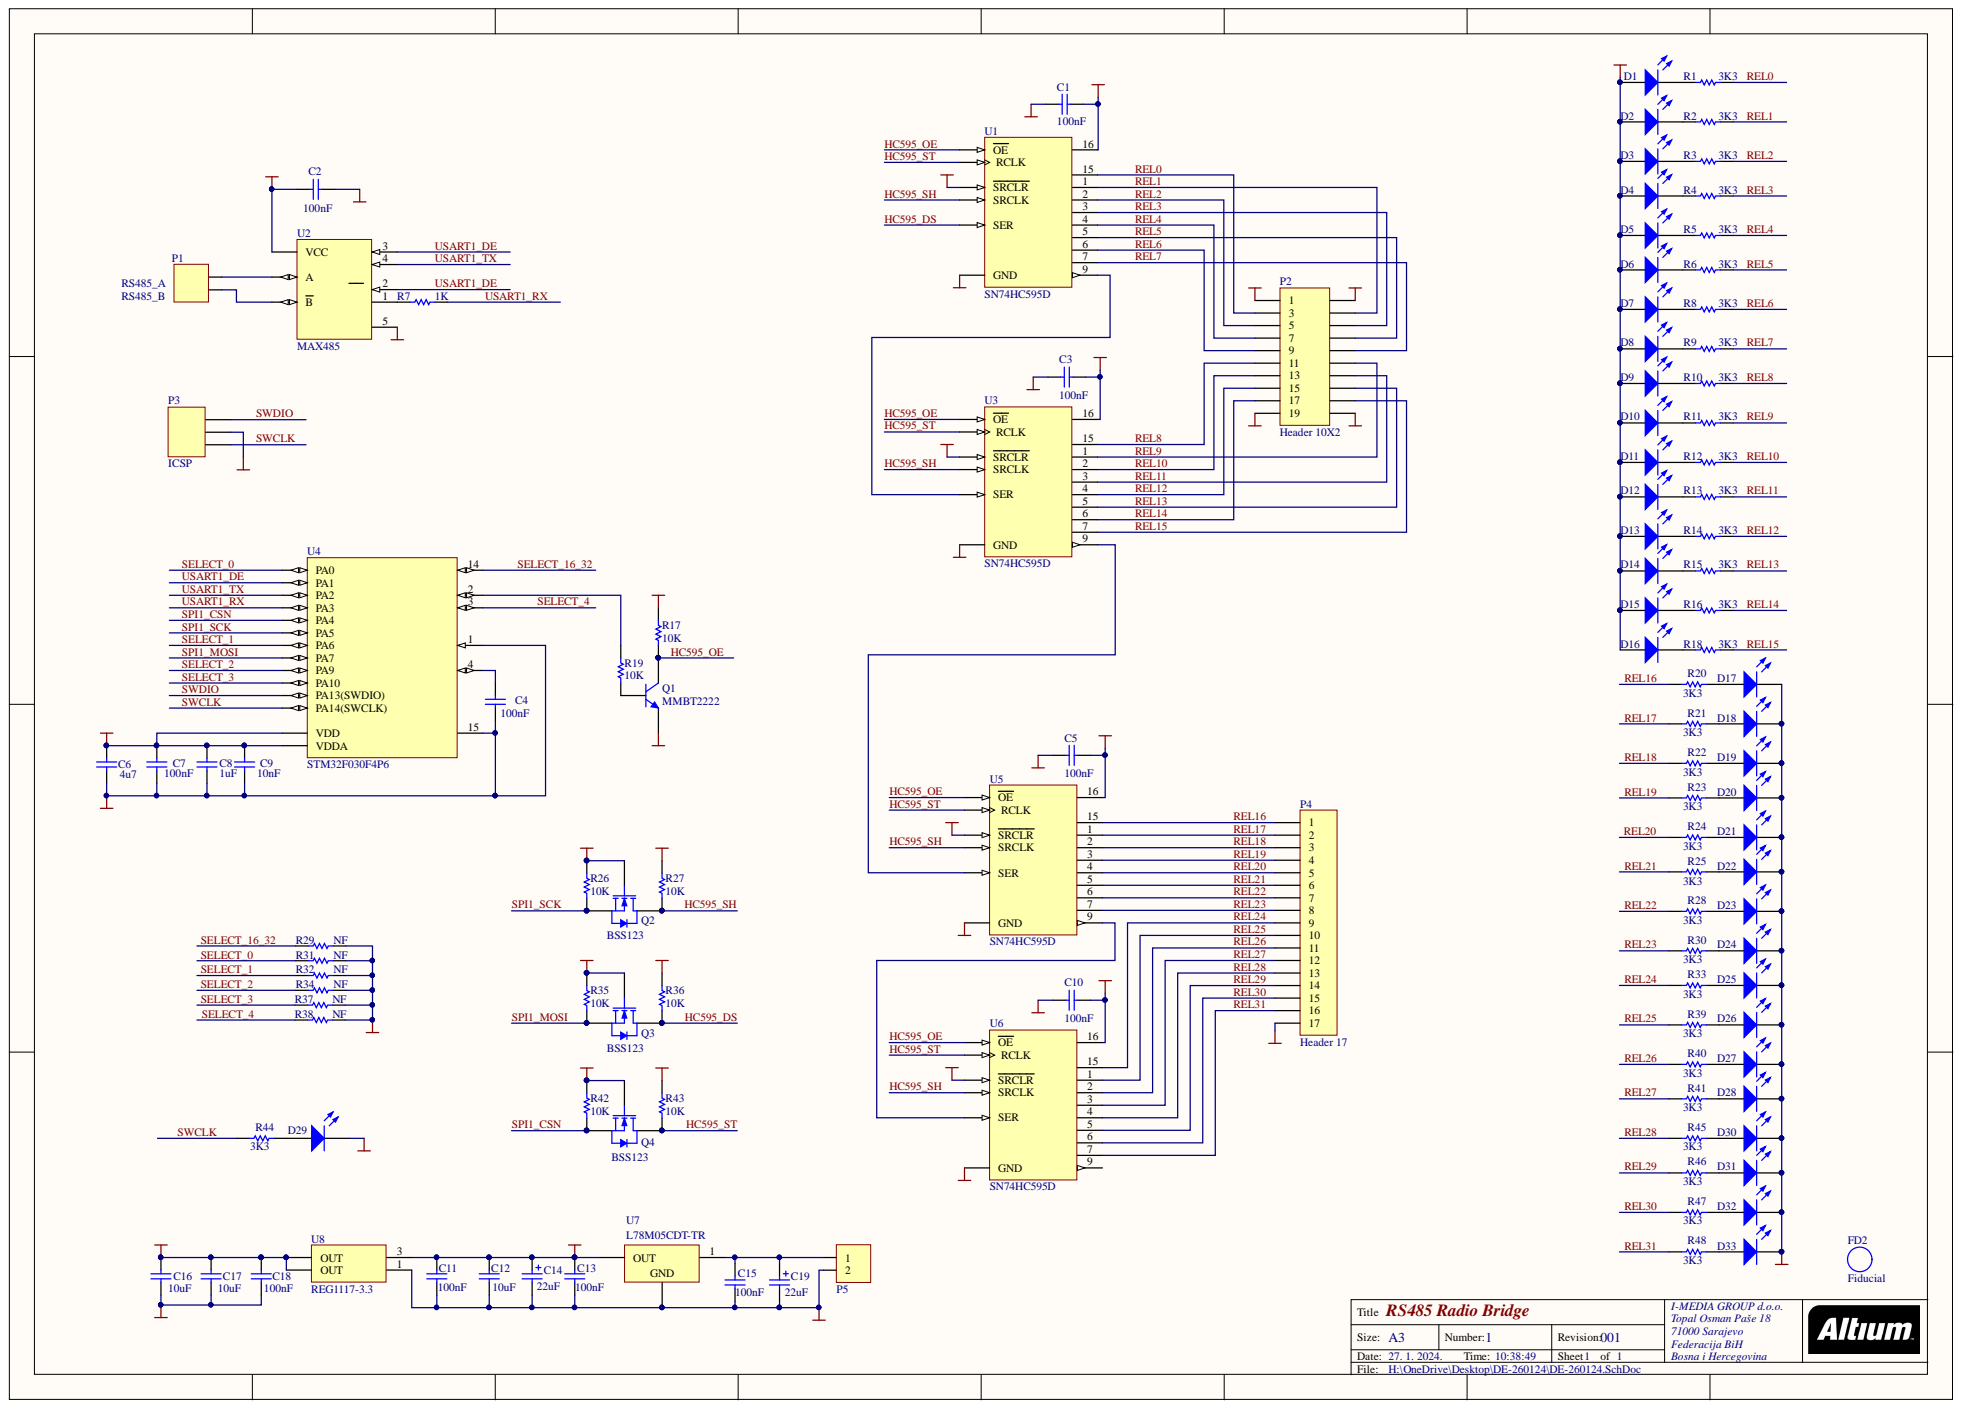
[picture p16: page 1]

R E L 4
R E L 5

P2Header 10X 7

R E L 9
R E L10
R E L 1 1
R E L12
R E L13
R E L14

R E L25
R E L26
R E L27

R E L29
R E L30
R E L31

RS485 Radio Br idge Ti t l e | I -MEDIA GR O UP d.o.o. Topal O s man P a še 18 71000 Sarajevo Federacija BiH Bosna i Hercegovina

Size: A 3 | Number : 1 | Revi s ion: 001
Date: Ti me: | | Sheet 1 of 1



Comment | Description | Designator | Footprint | LibRef | Quantity
100nF | Ceramic Chip Capacitor -Standard | C1, C2, C3, C4, C5, C7, C10, C11, C13, C15, C18 | 0603 | C0603 | 11

4u7 | Ceramic Chip Capacitor -Standard | C6 | 0805 | C0805 | 1

1uF | Ceramic Chip Capacitor -Standard | C8 | 0603 | C0603 | 1

10nF | Ceramic Chip Capacitor -Standard | C9 | 0603 | C0603 | 1

10uF | Ceramic Chip Capacitor -Standard | C12, C16, C17 | 0805 | C0805 | 3

22uF | Aluminum Electrolytic Capacitor, Radial Style with Long Leads: 47uF, 35V | C14, C19 | CAPPR2-5X11 | EKA00AA247F00 | 2

LED_RED | High Performance Chip LED, Red | D1, D2, D3, D4, D5, D6, D7, D8, D9, D10, D11, D12, D13, D14, D15, D16, D17, D18, D19, D20, D21, D22, D23, D24, D25, D26, D27, D28, D29, D30, D31, D32, D33 | 1.6X0.8X0.8 | HSMZ-C190 | 33

TERMINAL BLOK 2 | 2 pinski terminal blok | P1, P5 | TERMINAL BLOK 2 | TERMINAL BLOK 2 | 2

Header 10X2 | Header, 10-Pin, Dual row | P2 | HDR2X10 | Header 10X2 | 1

ICSP | Header, 3-Pin | P3 | HDR1X3 | Header 3 | 1
Header 17 | Header, 17-Pin | P4 | HDR1X17 | Header 17 | 1
MMBT2222 | NPN General-purpose Transistor | Q1 | SOT23_N | BC817 | 1

BSS123 | N-channel Enhancement Mode Vertical D-MOSFET | Q2, Q3, Q4 | SOT23_N | BSS123 | 3

3K3 | Rectangular Thick Film Chip Resistor, 10 Ohm to 330k Ohm Range, 0.1% and 0.5% Tolerance, 0603 Size, 0.063 W | R1, R2, R3, R4, R5, R6, R8, R9, R10, R11, R12, R13, R14, R15, R16, R18, R20, R21, R22, R23, R24, R25, R28, R30, R33, R39, R40, R41, R44, R45, R46, R47, R48 | ERA-0603 | ERA3Y | 33

1K | Rectangular Thick Film Chip Resistor, 10 Ohm to 1M Ohm Range, 0.1% and 0.5% Tolerance, 0805 Size, 0.1 W | R7 | ERA-0603 | ERA6Y | 1

10K | Rectangular Thick Film Chip Resistor, 10 Ohm to 1M Ohm Range, 0.1% and 0.5% Tolerance, 0805 Size, 0.1 W | R17, R19, R26, R27, R35, R36, R42, R43 | ERA-0603 | ERA6Y | 8

NF | Rectangular Thick Film Chip Resistor, 10 Ohm to 1M Ohm Range, 0.1% and 0.5% Tolerance, 0805 Size, 0.1 W | R29, R31, R32, R34, R37, R38 | ERA-0603 | ERA6Y | 6

SN74HC595D | 8-Bit Shift Register with 3-State Output Registers | U1, U3, U5, U6 | D016_N | SN74HC595D | 4

MAX485 | Differential Bus Transceiver | U2 | D008_L | SN75176BD | 1

STM32F030F4P6 | ARM Cortex-M0 32-bit MCU, 16 KB Flash, 4 KB Internal RAM, 15 I/Os, 20-pin TSSOP, -40 to 85 degC, Tube | U4 | STM-TSSOP20_N | STM32F030F4P6 | 1

L78M05CDT-TR | Positive Voltage Regulator, 5V, 3-Pin DPAK, Tape and Reel | U7 | TO-252_N | L78M05CDT-TR | 1

REG1117-3.3 | 800mA and 1A Low | U8 | ZZ311 | REG 1117- 3.3 | 1

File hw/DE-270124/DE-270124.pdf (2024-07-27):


A4 Size: | N umber: | 0 0 1 Rev i s i o n :
Date: 2 7. 1. 2 0 2 4 . T ime: 1 7 : 2 9 : 5 1 | | Sheet 1 o f 1



Footprint | Comment | LibRef | Designator | Description | Quantity

Style with Long Leads: 47uF, 35V

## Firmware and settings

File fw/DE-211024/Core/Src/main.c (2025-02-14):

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
/* Includes ------------------------------------------------------------------*/
#include "main.h"

/* USER CODE BEGIN Includes */
#include <stdio.h>
#include <string.h>
#include <stdarg.h>
#include <stdlib.h>
/* USER CODE END Includes */

/* USER CODE BEGIN PTD */
// Struktura za pracenje stanja releja
typedef struct {
    uint8_t last_state;
    uint32_t timer;  // Vreme kada je relej poslednji put pre�ao u PWM
} RelayState;

RelayState relayStates[8];  // Struktura za 8 releja
/* USER CODE END PTD */

/* USER CODE BEGIN PD */
#define DIMRXBUF_SIZE 16
#define NUMBER_OF_RELAY 8
#define MENU_TIMEOUT 10000 // 10 sekundi timeout
#define SHORT_PRESS_MIN 10  // 10 ms
#define SHORT_PRESS_MAX 200 // 200 ms
#define LONG_PRESS_MIN 1000 // 1 sekunda
#define RESET_PRESS_MIN 5000 // 5 sekunda
#define LONG_PRESS_INTERVAL 5 // Brzina promjene kod dugog pritiska
#define INCREMENT_STEP 5   // Korak inkrementacije za dugi pritisak
#define TOGGLE_INTERVAL 200 // Period treptanja LED
#define ERROR_TOGGLE_INTERVAL 50 // Period treptanja LED kod greï¿½ke
#define BUTTON_PAUSE    200 // dodatni debouncing 
/* USER CODE END PD */

CRC_HandleTypeDef hcrc;

I2C_HandleTypeDef hi2c1;

IWDG_HandleTypeDef hiwdg;

TIM_HandleTypeDef htim1;
TIM_HandleTypeDef htim3;

UART_HandleTypeDef huart1;

/* USER CODE BEGIN PV */
TinyFrame tfapp;

GPIO_TypeDef *LED_PORT[8] = {GPIOA, GPIOA, GPIOA, GPIOA, GPIOA, GPIOA, GPIOB, GPIOB};
uint16_t LED_PIN[8] = {GPIO_PIN_0, GPIO_PIN_1, GPIO_PIN_2, GPIO_PIN_3,GPIO_PIN_4 ,GPIO_PIN_5 ,GPIO_PIN_4 ,GPIO_PIN_5};

volatile uint8_t selected_channel = 7;
volatile uint8_t menu_activ = 0;
volatile uint32_t menu_timer = 0;
volatile uint8_t toggle_state = 0;
volatile uint8_t error_state = 0;
volatile uint32_t last_press_time = 0;
volatile uint32_t last_toggle_time = 0;
volatile uint32_t last_check_time = 0;
volatile uint32_t last_err_toggle_time = 0;
volatile uint32_t last_increment_time = 0;
uint8_t button_select_prev = 0, button_onoff_prev = 0;

// Definicije za stanja releja
uint8_t relay_states[8] = {0};      // Trenutnostanje releja
uint8_t relay_old_states[8] = {0};  // Flagovi promjene stanja releja
uint8_t relay_duty_cycle = 50;      // Pocetni duty cycle (50%)

static uint32_t current_tick = 0;   // trenutni vremenski otisak
static uint32_t pause_tick = 0;     // vremenski otisak za pauzu od 10000ms
static uint32_t pause = 100;
static uint8_t i = 0;               // trenutni broj releja
static uint8_t t = 0;               // stanje releja (0 ili 1)

static uint8_t my_address = 0;
static uint16_t rel_start = 0;
static uint16_t rel_end = 0;
bool init_tf = false;
bool restart = false;
uint8_t rec, multiplier = 1;
/* USER CODE END PV */

void SystemClock_Config(void);
static void MX_GPIO_Init(void);
static void MX_CRC_Init(void);
static void MX_I2C1_Init(void);
static void MX_IWDG_Init(void);
static void MX_TIM1_Init(void);
static void MX_TIM3_Init(void);
static void MX_USART1_UART_Init(void);
/* USER CODE BEGIN PFP */
void RS485_Init(void);
/* USER CODE END PFP */

/* USER CODE BEGIN 0 */
/**
  * @brief  staticka inline funkcija pauze 1~2ms za kašnjenje odgovora za stabilne repeatere
  *         u interruptu se ne može koristiti HAL_GetTick ni HAL_Delay tako da ova funkcija
  *         obezbjeduje kašnjenje oko 1 ms bez hal drivera gubljenjem vremena izvršavanjem
  *         ciklusa koji ne rade ništa
  * @param
  * @retval
  */
static inline void delay_us(uint32_t us) {
    volatile uint32_t cycles = (HAL_RCC_GetHCLKFreq() / 20000000) * us;  // Smanjen faktor
    while (cycles--) {
        __asm volatile("NOP");  // Izbegava optimizaciju
    }
}
/**
  * @brief  mali efekt sa LED diodama prednjeg panela kod ukljucenja
  * @param
  * @retval
  */
void start_effect(void) {
    const uint8_t order[][2] = {
        {4, 5}, {3, 6}, {2, 7}, {1, 8}, // Paljenje
        {4, 5}, {3, 6}, {2, 7}, {1, 8}  // Gašenje
    };
    HAL_Delay(300);
    for (int i = 0; i < 8; i++) {
        GPIO_PinState state = (i < 4) ? GPIO_PIN_SET : GPIO_PIN_RESET;
        HAL_GPIO_WritePin(LED_PORT[order[i][0] - 1], LED_PIN[order[i][0] - 1], state);
        HAL_GPIO_WritePin(LED_PORT[order[i][1] - 1], LED_PIN[order[i][1] - 1], state);
        HAL_Delay(50);
#ifdef USE_WATCHDOG
        HAL_IWDG_Refresh(&hiwdg);
#endif
    }
}
/**
  * @brief  podesi adresu modula dimera na busu prema poziciji DIP switcha
  * @param
  * @retval
  */
void get_address(void)
{
    my_address = 0;
    if ((HAL_GPIO_ReadPin(ADDRESS_0_GPIO_Port, ADDRESS_0_Pin) == GPIO_PIN_RESET))   my_address |= 0x01;
    if ((HAL_GPIO_ReadPin(ADDRESS_1_GPIO_Port, ADDRESS_1_Pin) == GPIO_PIN_RESET))   my_address |= 0x02;
    if ((HAL_GPIO_ReadPin(ADDRESS_2_GPIO_Port, ADDRESS_2_Pin) == GPIO_PIN_RESET))   my_address |= 0x04;
    if ((HAL_GPIO_ReadPin(ADDRESS_3_GPIO_Port, ADDRESS_3_Pin) == GPIO_PIN_RESET))   my_address |= 0x08;
    if ((HAL_GPIO_ReadPin(ADDRESS_4_GPIO_Port, ADDRESS_4_Pin) == GPIO_PIN_RESET))   my_address |= 0x10;
    if ((HAL_GPIO_ReadPin(ADDRESS_5_GPIO_Port, ADDRESS_5_Pin) == GPIO_PIN_RESET))   my_address |= 0x20;
    if(my_address)
    {
        rel_start = (NUMBER_OF_RELAY*multiplier*(my_address-1))+1;
        rel_end = rel_start + (NUMBER_OF_RELAY*multiplier)-1;
    }
}
/**
  * @brief  funkcija za kontrolu releja koja kod uključenja relej starta sa punim izlazom a nakon
  *         inicijalnog stanja prelazi u 60% pwm mod, tako da je grijanje releja svedeno na minimum
  * @param
  * @retval
  */
void relay_update(uint8_t relay_num, uint8_t state)
{
    static uint32_t last_state[8] = {0};        // flag prošlog stanaja tako da sam o prva promjena utiče na funkciju
    static uint32_t last_change_time[8] = {0};  // Čuvanje vremena poslednje promene stanja za svaki relej
    static uint32_t pwm_duty_cycle[8] = {0};  // Početni duty cycle za svaki relej (100% kada je uključen)
    uint32_t current_tick = HAL_GetTick();      // Vreme u milisekundama

    // Proveri sve releje svaki put kada se funkcija pozove
    for (int i = 0; i < 8; i++) {
        // Ako je prošlo više od 1000 ms (1 sekunda) od poslednje promene za taj relej
        if (current_tick - last_change_time[i] >= 1000) {
            if (pwm_duty_cycle[i] == 100) {
                pwm_duty_cycle[i] = 60;  // Prebaci PWM na 60% nakon 1 sekunde
            }
        }
    }

    // Ako je stanje 1 (uključi relej)
    if ((state == 1) && !last_state[relay_num]) {
        last_state[relay_num] = state;
        last_change_time[relay_num] = current_tick;  // Ažuriraj poslednje vreme kada je stanje promenjeno
        pwm_duty_cycle[relay_num] = 100;  // PWM na 100%
    }
    // Ako je stanje 0 (isključi relej)
    else if ((state == 0) && last_state[relay_num]) {
        last_state[relay_num] = state;
        pwm_duty_cycle[relay_num] = 0;  // Postavi PWM na 0%
        last_change_time[relay_num] = current_tick;  // Ažuriraj poslednje vreme kada je stanje promenjeno
    }

    __HAL_TIM_SET_COMPARE(&htim1, TIM_CHANNEL_1, (htim1.Init.Period + 1) * pwm_duty_cycle[0] / 100);
    __HAL_TIM_SET_COMPARE(&htim1, TIM_CHANNEL_2, (htim1.Init.Period + 1) * pwm_duty_cycle[1] / 100);
    __HAL_TIM_SET_COMPARE(&htim1, TIM_CHANNEL_3, (htim1.Init.Period + 1) * pwm_duty_cycle[2] / 100);
    __HAL_TIM_SET_COMPARE(&htim1, TIM_CHANNEL_4, (htim1.Init.Period + 1) * pwm_duty_cycle[3] / 100);
    __HAL_TIM_SET_COMPARE(&htim3, TIM_CHANNEL_1, (htim3.Init.Period + 1) * pwm_duty_cycle[4] / 100);
    __HAL_TIM_SET_COMPARE(&htim3, TIM_CHANNEL_2, (htim3.Init.Period + 1) * pwm_duty_cycle[5] / 100);
    __HAL_TIM_SET_COMPARE(&htim3, TIM_CHANNEL_3, (htim3.Init.Period + 1) * pwm_duty_cycle[6] / 100);
    __HAL_TIM_SET_COMPARE(&htim3, TIM_CHANNEL_4, (htim3.Init.Period + 1) * pwm_duty_cycle[7] / 100);

    for(int i = 0; i < 8; i++)
    {
        relay_states[i] = (pwm_duty_cycle[i] > 0) ? 1:0;

    }
}
/**
  * @brief  kopira stanje izlaza na LED prednjeg panela
  * @param
  * @retval
  */
void refresh_led(void)
{
    for (uint8_t i = 0; i < 8; i++)
    {
        HAL_GPIO_WritePin(LED_PORT[i], LED_PIN[i], (relay_states[i] > 0) ? GPIO_PIN_SET : GPIO_PIN_RESET);
    }
}
/**
  * @brief  reaguje na pritisak tastera na prednjem panelu modula
  * @param
  * @retval
  */
void handle_buttons(void)
{
    uint32_t current_time = HAL_GetTick();
    uint8_t button_select = HAL_GPIO_ReadPin(GPIOB, GPIO_PIN_2);
    uint8_t button_onoff = HAL_GPIO_ReadPin(GPIOB, GPIO_PIN_3);

    if (button_select == GPIO_PIN_RESET) {
        if (!button_select_prev) {
            button_select_prev = 1; // lock press time load
            menu_activ = 1;
            toggle_state = 1;
            if(++selected_channel > 7) selected_channel = 0;
            menu_timer = current_time + MENU_TIMEOUT;
            last_press_time = current_time; // load first press time
            refresh_led();
            get_address();
            HAL_Delay(BUTTON_PAUSE);
        }
        else if (error_state && (current_time - last_press_time > RESET_PRESS_MIN))
        {

        }
    }
    else if ((button_select == GPIO_PIN_SET) && button_select_prev)
    {
        button_select_prev = 0;
        HAL_Delay(BUTTON_PAUSE);
        refresh_led();
    }

    if (menu_activ && (button_onoff == GPIO_PIN_RESET)) {
        if (!button_onoff_prev) {
            button_onoff_prev = 1; // lock press time load
            last_press_time = current_time; // load first press time
            if(relay_states[selected_channel] > 0) relay_states[selected_channel] = 0;
            else relay_states[selected_channel] = 1;

            HAL_Delay(BUTTON_PAUSE);
        }
        menu_timer = current_time + MENU_TIMEOUT;
    }
    else if ((button_onoff == GPIO_PIN_SET) && button_onoff_prev)
    {
        button_onoff_prev = 0; // release button press
        HAL_Delay(BUTTON_PAUSE);
    }
}
/**
  * @brief  logika korisnickog menija sa led diodama i tasterima na prednjem panelu modula
  * @param
  * @retval
  */
void menu_logic(void)
{
    uint32_t current_time = HAL_GetTick();

    if (current_time > menu_timer) {
        selected_channel = 7;
        menu_activ = 0;
        toggle_state = 0;
        refresh_led();
    }

    // Definiši vremenske intervale zavisno od relay_states
    uint32_t on_time, off_time;
    if (relay_states[selected_channel] == 1) {
        on_time = TOGGLE_INTERVAL * 3;  // LED ON 3x duže
        off_time = TOGGLE_INTERVAL;     // LED OFF normalno
    } else {
        on_time = TOGGLE_INTERVAL;      // LED ON normalno
        off_time = TOGGLE_INTERVAL * 3; // LED OFF 75% duže
    }

    uint32_t toggle_period = toggle_state ? on_time : off_time;

    if (current_time - last_toggle_time >= toggle_period) {
        HAL_GPIO_TogglePin(LED_PORT[selected_channel], LED_PIN[selected_channel]);
        toggle_state = !toggle_state;  // Promena stanja
        last_toggle_time = current_time;
    }
}
/**
  * @brief  funkcija obezbjeđuje ispravan poziv update releja kod 
  *         brze izmjene stanja sa busa, svaki relej će preći iz 
  *         100% u 60% pwm mod kada je uključen
  * @param
  * @retval
  */
void set_relay(void)
{
    static uint32_t set_tmr = 0;
    for(int i = 0; i < NUMBER_OF_RELAY; i++)
    {
        if(relay_states[i] != relay_old_states[i])
        {
            set_tmr = HAL_GetTick();
            relay_old_states[i] = relay_states[i];
            relay_update(i, relay_states[i]);
        }
    }
    if(set_tmr && ((HAL_GetTick() - set_tmr) >= 1000))
    {
        set_tmr = 0;
        for(int i = 0; i < NUMBER_OF_RELAY; i++)
        {
            relay_update(i, relay_states[i]);
        }
    }
}
/* USER CODE END 0 */

/**
  * @brief  The application entry point.
  * @retval int
  */
int main(void)
{

    /* MCU Configuration--------------------------------------------------------*/

    /* Reset of all peripherals, Initializes the Flash interface and the Systick. */
    HAL_Init();

    /* Configure the system clock */
    SystemClock_Config();

    /* Initialize all configured peripherals */
    MX_GPIO_Init();
    MX_CRC_Init();
    MX_I2C1_Init();
    MX_IWDG_Init();
    MX_TIM1_Init();
    MX_TIM3_Init();
    MX_USART1_UART_Init();
    /* USER CODE BEGIN 2 */
    RS485_Init();
    start_effect();
    start_effect();
    start_effect();
    get_address();
    /* USER CODE END 2 */

    /* Infinite loop */
    /* USER CODE BEGIN WHILE */
    while (1)
    {
        if(restart == true) Error_Handler();
        handle_buttons();
        menu_logic();
        /* USER CODE END WHILE */

        /* USER CODE BEGIN 3 */
        set_relay();

#ifdef USE_WATCHDOG
        HAL_IWDG_Refresh(&hiwdg);
#endif
    }
    /* USER CODE END 3 */
}

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
/* USER CODE BEGIN 4 */
/**
  * @brief  Sluša bus za paket sa BINARY_SET tipom i provjerava adresirani izlaz 
  *         ako je u sopstvenom opsegu reaguje na ostale ne odgovara
  * @param
  * @retval
  */
TF_Result BINARY_SET_Listener(TinyFrame *tf, TF_Msg *msg)
{
    uint8_t res = 0;
    uint16_t adr = (uint16_t) (msg->data[0] << 8) | msg->data[1]; // Kombinacija dva bajta u adresu
    uint8_t idx = adr - rel_start; // Izračunavanje indeksa releja
    uint8_t ret[4]; // Niz za vraćanje stanja

    // Proveravamo da li je adresa unutar opsega rel_start i rel_end
    if (my_address && adr && (adr >= rel_start) && (adr <= rel_end)) {

        if (msg->data[2] == 0x01) {
            relay_states[idx] = 1;  // Uključivanje releja
        } else if (msg->data[2] == 0x02) {
            relay_states[idx] = 0;  // Isključivanje releja
        }
        res++;  // Povećavamo broj uspešnih operacija
    }

    // Ako je došlo do promene stanja, vraćamo novo stanje
    if (res == 1) {
        ret[0] = msg->data[0];
        ret[1] = msg->data[1];
        if (relay_states[idx] == 1) {
            ret[2] = 1;  // Stanje 1 (ON)
        } else {
            ret[2] = 2;  // Stanje 2 (OFF)
        }
        ret[3] = ACK;
        msg->data = ret;  // Postavljamo novi niz za odgovor
        msg->len = 4;  // Dužina odgovora je 4
        TF_Respond(tf, msg);  // Odgovaramo sa novim stanjem
    }

    return TF_STAY;  // Održavanje trenutnog stanja
}
/**
  * @brief  Sluša bus za paket sa BINARY_GET tipom i provjerava adresirani izlaz 
  *         ako je u sopstvenom opsegu odgovara sa stanjem na ostale ne odgovara
  * @param
  * @retval
  */
TF_Result BINARY_GET_Listener(TinyFrame *tf, TF_Msg *msg)
{
    uint16_t adr = (uint16_t) (msg->data[0] << 8) | msg->data[1]; // Kombinacija dva bajta u adresu
    uint8_t idx = adr - rel_start; // Izračunavanje indeksa releja
    uint8_t ret[3]; // Niz za vraćanje stanja

    // Proveravamo da li je adresa unutar opsega rel_start i rel_end
    if (my_address && adr && (adr >= rel_start) && (adr <= rel_end)) {
        ret[0] = msg->data[0];
        ret[1] = msg->data[1];
        if (relay_states[idx] == 1) {
            ret[2] = 1;  // Stanje 1 (ON)
        } else {
            ret[2] = 2;  // Stanje 2 (OFF)
        }
        msg->data = ret;  // Postavljamo novi niz za odgovor
        msg->len = 3;  // Dužina odgovora je 3
        TF_Respond(tf, msg);  // Odgovaramo sa novim stanjem
    }

    return TF_STAY;  // Održavanje trenutnog stanja
}
/**
  * @brief  Sluša bus za paket sa BINARY_RESET tipom i provjerava adresirani izlaz 
  *         ako je u sopstvenom opsegu setuje flag odgovara i nakon odogovora pokreće reset
  * @param
  * @retval
  */
TF_Result BINARY_RESET_Listener(TinyFrame *tf, TF_Msg *msg)
{
    uint16_t adr = (uint16_t) (msg->data[0] << 8) | msg->data[1]; // Kombinacija dva bajta u adresu
    uint8_t idx = adr - rel_start; // Izračunavanje indeksa releja
    uint8_t ret[3]; // Niz za vraćanje stanja

    // Proveravamo da li je adresa unutar opsega rel_start i rel_end
    if (my_address && adr && (adr >= rel_start) && (adr <= rel_end)) {
        restart = true; // setujemo flag a ne restartujemo odmah da bi vratili odgovor
        ret[0] = msg->data[0];
        ret[1] = msg->data[1];
        ret[2] = ACK; 
        msg->data = ret;  // Postavljamo novi niz za odgovor
        msg->len = 3;  // Dužina odgovora je 3
        TF_Respond(tf, msg);  // Odgovaramo sa novim stanjem
    }

    return TF_STAY;  // Održavanje trenutnog stanja
}
/**
  * @brief
  * @param
  * @retval
  */
void RS485_Init(void)
{
    if(!init_tf) {
        init_tf = TF_InitStatic(&tfapp, TF_SLAVE);
        TF_AddTypeListener(&tfapp, BINARY_GET, BINARY_GET_Listener);
        TF_AddTypeListener(&tfapp, BINARY_SET, BINARY_SET_Listener);
        TF_AddTypeListener(&tfapp, BINARY_RESET, BINARY_RESET_Listener);
    }
    HAL_UART_Receive_IT(&huart1, &rec, 1);
}
/**
  * @brief
  * @param
  * @retval
  */
void RS485_Tick(void)
{
    if (init_tf == true) {
        TF_Tick(&tfapp);
    }
}
/**
  * @brief
  * @param
  * @retval
  */
void TF_WriteImpl(TinyFrame *tf, const uint8_t *buff, uint32_t len)
{
    delay_us(2000); // puza kod odgovora zbog repeatera na linji 
    HAL_UART_Transmit(&huart1,(uint8_t*)buff, len, RESP_TOUT);
    HAL_UART_Receive_IT(&huart1, &rec, 1);
}
/**
  * @brief
  * @param
  * @retval
  */
void HAL_UART_RxCpltCallback(UART_HandleTypeDef *huart)
{
    TF_AcceptChar(&tfapp, rec);
    HAL_UART_Receive_IT(&huart1, &rec, 1);
}
/**
  * @brief
  * @param
  * @retval
  */
void HAL_UART_TxCpltCallback(UART_HandleTypeDef *huart)
{
}
/**
  * @brief
  * @param
  * @retval
  */
void HAL_UART_ErrorCallback(UART_HandleTypeDef *huart)
{
    __HAL_UART_CLEAR_PEFLAG(&huart1);
    __HAL_UART_CLEAR_FEFLAG(&huart1);
    __HAL_UART_CLEAR_NEFLAG(&huart1);
    __HAL_UART_CLEAR_IDLEFLAG(&huart1);
    __HAL_UART_CLEAR_OREFLAG(&huart1);
    HAL_UART_AbortReceive(&huart1);
    HAL_UART_Receive_IT(&huart1, &rec, 1);
}
/* USER CODE END 4 */
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


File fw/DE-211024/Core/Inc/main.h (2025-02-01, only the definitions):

#define LED1_Pin GPIO_PIN_0
#define LED1_GPIO_Port GPIOA
#define LED2_Pin GPIO_PIN_1
#define LED2_GPIO_Port GPIOA
#define LED3_Pin GPIO_PIN_2
#define LED3_GPIO_Port GPIOA
#define LED4_Pin GPIO_PIN_3
#define LED4_GPIO_Port GPIOA
#define LED5_Pin GPIO_PIN_4
#define LED5_GPIO_Port GPIOA
#define LED6_Pin GPIO_PIN_5
#define LED6_GPIO_Port GPIOA
#define RELAY5_Pin GPIO_PIN_6
#define RELAY5_GPIO_Port GPIOA
#define RELAY6_Pin GPIO_PIN_7
#define RELAY6_GPIO_Port GPIOA
#define RELAY7_Pin GPIO_PIN_0
#define RELAY7_GPIO_Port GPIOB
#define RELAY8_Pin GPIO_PIN_1
#define RELAY8_GPIO_Port GPIOB
#define BUTTON_SELECT_Pin GPIO_PIN_2
#define BUTTON_SELECT_GPIO_Port GPIOB
#define ADDRESS_0_Pin GPIO_PIN_10
#define ADDRESS_0_GPIO_Port GPIOB
#define ADDRESS_1_Pin GPIO_PIN_11
#define ADDRESS_1_GPIO_Port GPIOB
#define ADDRESS_2_Pin GPIO_PIN_12
#define ADDRESS_2_GPIO_Port GPIOB
#define ADDRESS_3_Pin GPIO_PIN_13
#define ADDRESS_3_GPIO_Port GPIOB
#define ADDRESS_4_Pin GPIO_PIN_14
#define ADDRESS_4_GPIO_Port GPIOB
#define ADDRESS_5_Pin GPIO_PIN_15
#define ADDRESS_5_GPIO_Port GPIOB
#define RELAY1_Pin GPIO_PIN_8
#define RELAY1_GPIO_Port GPIOA
#define RELAY2_Pin GPIO_PIN_9
#define RELAY2_GPIO_Port GPIOA
#define RELAY3_Pin GPIO_PIN_10
#define RELAY3_GPIO_Port GPIOA
#define RELAY4_Pin GPIO_PIN_11
#define RELAY4_GPIO_Port GPIOA
#define BUTTON_ON_OFF_Pin GPIO_PIN_3
#define BUTTON_ON_OFF_GPIO_Port GPIOB
#define LED7_Pin GPIO_PIN_4
#define LED7_GPIO_Port GPIOB
#define LED8_Pin GPIO_PIN_5
#define LED8_GPIO_Port GPIOB

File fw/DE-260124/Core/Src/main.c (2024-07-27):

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
/* Includes ------------------------------------------------------------------*/
#include "main.h"

/* USER CODE BEGIN PTD */
typedef enum{
    READY = 0,
    RECEIVED,
}led_status_td;
/* USER CODE END PTD */

/* USER CODE BEGIN PM */
#define HC_STROBE() HAL_GPIO_WritePin(HC595_STROBE_GPIO_Port, HC595_STROBE_Pin, GPIO_PIN_RESET),\
                    HAL_GPIO_WritePin(HC595_STROBE_GPIO_Port, HC595_STROBE_Pin, GPIO_PIN_SET);
/* USER CODE END PM */

IWDG_HandleTypeDef hiwdg;

SPI_HandleTypeDef hspi1;

UART_HandleTypeDef huart1;
CRC_HandleTypeDef hcrc;
/* USER CODE BEGIN PV */
TinyFrame tfapp;
uint8_t sel = 0;
uint16_t rel_start, rel_end;
bool init_tf = false;
uint8_t rel[4] = {0,0,0xff,0xff};
uint8_t rel_old[4] = {0,0,0xff,0xff};
uint8_t rec, ml = 1;
led_status_td led_status = READY;
/* USER CODE END PV */

void SystemClock_Config(void);
static void MX_GPIO_Init(void);
static void MX_IWDG_Init(void);
static void MX_SPI1_Init(void);
static void MX_USART1_UART_Init(void);
/* USER CODE BEGIN PFP */
void RS485_Tick(void);
void Error_Handler(void);
void RS485_Init(void);
void sys_init(void);
TF_Result ID_Listener(TinyFrame *tf, TF_Msg *msg);
TF_Result GEN_Listener(TinyFrame *tf, TF_Msg *msg);
TF_Result TYPE_Listener(TinyFrame *tf, TF_Msg *msg);
TF_Result STATUS_Listener(TinyFrame *tf, TF_Msg *msg);
/* USER CODE END PFP */

/**
  * @brief  The application entry point.
  * @retval int
  */
int main(void){
  /* USER CODE BEGIN 1 */
uint8_t i;
uint32_t rcnt,rsta = 0,cnt = 0;
  /* USER CODE END 1 */

  /* MCU Configuration--------------------------------------------------------*/

  /* Reset of all peripherals, Initializes the Flash interface and the Systick. */
  HAL_Init();

  /* Configure the system clock */
  SystemClock_Config();

  /* Initialize all configured peripherals */
  MX_GPIO_Init();
#ifdef USE_WATCHDOG
  MX_IWDG_Init();
#endif  
  MX_SPI1_Init();
  MX_USART1_UART_Init();
  /* USER CODE BEGIN 2 */
  RS485_Init();
  sys_init();
  /* USER CODE END 2 */

  /* Infinite loop */
  /* USER CODE BEGIN WHILE */
  while (1)
  {
      
    /* USER CODE END WHILE */

    /* USER CODE BEGIN 3 */
    for(i=0;i<4;i++)
    {
        if(rel_old[i] != rel[i])
        {
            rel_old[i] = rel[i];
            HAL_SPI_Transmit(&hspi1, rel, 4, 100);
            HC_STROBE();
        }
    }
    
    switch(led_status){
        case READY:
            if(!rsta){
                rcnt = HAL_GetTick();
                ++rsta;
            }else if((HAL_GetTick() - rcnt) >= 500U){
                rsta = 0;
                if(HAL_GPIO_ReadPin(STATUS_LED_GPIO_Port, STATUS_LED_Pin) == GPIO_PIN_SET){
                    HAL_GPIO_WritePin(STATUS_LED_GPIO_Port, STATUS_LED_Pin, GPIO_PIN_RESET);
                } else HAL_GPIO_WritePin(STATUS_LED_GPIO_Port, STATUS_LED_Pin, GPIO_PIN_SET);
            }
            break;
            
        case RECEIVED:
        default:    
            if(!rsta){
                rcnt = HAL_GetTick();
                ++rsta;
            }else if((HAL_GetTick() - rcnt) >= 50U){
                rsta = 0;
                if(HAL_GPIO_ReadPin(STATUS_LED_GPIO_Port, STATUS_LED_Pin) == GPIO_PIN_SET){
                    HAL_GPIO_WritePin(STATUS_LED_GPIO_Port, STATUS_LED_Pin, GPIO_PIN_RESET);
                } else HAL_GPIO_WritePin(STATUS_LED_GPIO_Port, STATUS_LED_Pin, GPIO_PIN_SET);
                if(++cnt > 10){
                    cnt = 0;
                    led_status = READY;
                }
            }
            break;
    }    
    HAL_Delay(10);
#ifdef USE_WATCHDOG
    HAL_IWDG_Refresh(&hiwdg);
#endif    
  }
  /* USER CODE END 3 */
}

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
/* USER CODE BEGIN 4 */
void sys_init(void){
    if(HAL_GPIO_ReadPin(SELECT_0_GPIO_Port, SELECT_0_Pin) == GPIO_PIN_RESET) sel |= 0x01U;
    if(HAL_GPIO_ReadPin(SELECT_1_GPIO_Port, SELECT_1_Pin) == GPIO_PIN_RESET) sel |= 0x02U;
    if(HAL_GPIO_ReadPin(SELECT_2_GPIO_Port, SELECT_2_Pin) == GPIO_PIN_RESET) sel |= 0x04U;
    if(HAL_GPIO_ReadPin(SELECT_3_GPIO_Port, SELECT_3_Pin) == GPIO_PIN_RESET) sel |= 0x08U;
    if(HAL_GPIO_ReadPin(SELECT_4_GPIO_Port, SELECT_4_Pin) == GPIO_PIN_RESET) sel |= 0x10U;
    if(HAL_GPIO_ReadPin(SELECT_16_32_GPIO_Port, SELECT_16_32_Pin) == GPIO_PIN_RESET) ml = 2;
    rel_start = (16*ml*sel)+1;
    rel_end = rel_start + (16*ml)-1;
    HAL_SPI_Transmit(&hspi1, rel, 4, 100);
    HC_STROBE();
    HAL_GPIO_WritePin(HC595_ENABLE_GPIO_Port, HC595_ENABLE_Pin, GPIO_PIN_SET);
}
/**
  * @brief
  * @param
  * @retval
  */
TF_Result ID_Listener(TinyFrame *tf, TF_Msg *msg){
    return TF_CLOSE;
}
/**
  * @brief
  * @param
  * @retval
  */
TF_Result GEN_Listener(TinyFrame *tf, TF_Msg *msg){    
    return TF_STAY;
}
/**
  * @brief
  * @param
  * @retval
  */
TF_Result STATUS_Listener(TinyFrame *tf, TF_Msg *msg){
    uint16_t adr = ((msg->data[0]<<8)|msg->data[1]);
    uint8_t ret[8];
    if ((adr >= rel_start)&&(adr <= rel_end)){
        ret[0] = rel_start<<8;
        ret[1] = rel_start & 0xFF;
        ret[2] = rel_end<<8;
        ret[3] = rel_end & 0xFF;
        ret[4] = rel[0];
        ret[5] = rel[1];
        ret[6] = ~rel[2];
        ret[7] = ~rel[3];
        msg->data = ret;
        msg->len = 8;
        if(ml == 1){
            ret[4] = ~rel[2];
            ret[5] = ~rel[3];
            msg->len = 6;
        }
        led_status = RECEIVED;
        TF_Respond(tf, msg);   
    }
    return TF_STAY;
}
/**
  * @brief
  * @param
  * @retval
  */
TF_Result BINARY_Listener(TinyFrame *tf, TF_Msg *msg){
    uint8_t idx, pos, res = 0, dpos = 2, apos = 3;   
    uint16_t adr = ((msg->data[0]<<8)|msg->data[1]);
    uint8_t ret[8];
    while((dpos < msg->len) && adr){
        if ((adr >= rel_start) && (adr <= (rel_end -((ml-1)*16)))){
            idx = (3-((adr-rel_start)/8));
            pos = (adr-rel_start)-((3-idx)*8);
            if (!msg->data[dpos]) rel[idx] |=  (1U<<pos);
            else rel[idx] &= ~(1U<<pos);
            res = 1;
        }
        if ((ml == 2) && (adr >= (rel_start + ((ml-1)*16))) && (adr <= rel_end)){
            idx = (3-((adr-rel_start)/8));
            pos = (adr-rel_start)-((3-idx)*8);
            if (!msg->data[dpos]) rel[idx] &= ~(1U<<pos);
            else rel[idx] |=  (1U<<pos);
            res = 1;
        }
        adr = ((msg->data[apos]<<8)|msg->data[apos+1]);
        apos += 3;
        dpos += 3;
    }
    if(res){
        led_status = RECEIVED;
        ret[0] = rel_start<<8;
        ret[1] = rel_start & 0xFF;
        ret[2] = rel_end<<8;
        ret[3] = rel_end & 0xFF;
        ret[4] = rel[0];
        ret[5] = rel[1];
        ret[6] = ~rel[2];
        ret[7] = ~rel[3];
        msg->data = ret;
        msg->len = 8;
        if(ml == 1){
            ret[4] = ~rel[2];
            ret[5] = ~rel[3];
            msg->len = 6;
        }
        TF_Respond(tf, msg);
    }
    return TF_STAY;
}
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

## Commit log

2024-07-27 firs commit
    [DE-260124.GBL, DE-260124.GBO, DE-260124.GBP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]
2024-10-23 hw final
    [DE-211024.PcbDoc, DE-211024.PcbLib, DE-211024.PrjPcb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]

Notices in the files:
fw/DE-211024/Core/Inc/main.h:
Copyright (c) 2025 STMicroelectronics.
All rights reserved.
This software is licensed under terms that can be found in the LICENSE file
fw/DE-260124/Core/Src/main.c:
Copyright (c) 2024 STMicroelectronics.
